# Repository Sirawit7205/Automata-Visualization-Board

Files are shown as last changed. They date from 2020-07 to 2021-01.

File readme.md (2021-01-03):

# CMOS Elementary Automata Visualization Board

This is an  open-source KiCad design files for a circuit that could generate and visualize [Elementary Automata](https://mathworld.wolfram.com/ElementaryCellularAutomaton.html) only by using common logic ICs. There are two versions available: Standard and Minimal. 

## Standard Version

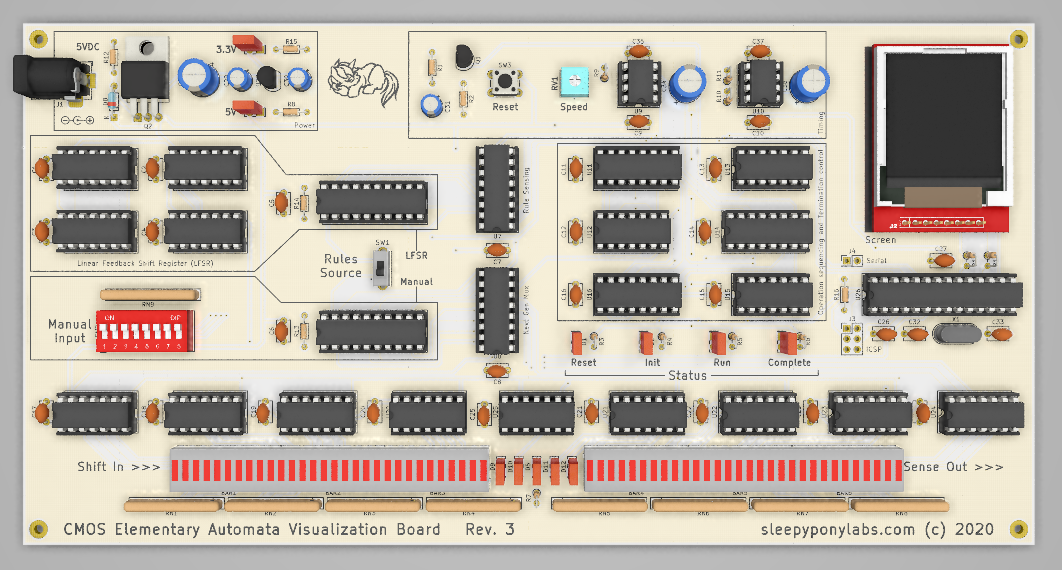
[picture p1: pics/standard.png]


Standard version is a large board of size 247x127mm (9.7x5in), suitable for putting in a frame. Featuring:

 - 26 Logic ICs in DIP package. (Okay, I have an ATMEGA328 here but it's here just to drive the display. Its firmware is available here as well.)
 - 1.44 inch TFT display with a display driver which can draws a complete picture of that elementary automata rule.
 - Fully visualized 65-bit shift register so you can see how the data flows.
 - Fully selectable 8-bit automata rule input.
 - An LSFR pseudo-random rules generator.
 - Status display.
 - Drawing speed adjustment.
 - All through hole design. Should be relatively easy to solder.

We are currently at Revision 3. Changelog is below:

**Revision 3 (July 2020)**
 - Fixed all of the issues found in rev 2.
 - BOMs consolidated to lessen the unique parts count.
 - New LFSR circuit, the rare CD4006 is no longer required.
 - Updated all footprints to the latest version.
 - Minor changes to the appearances of the PCB.

**Revision 2 (May 2020)**
 - Fixed Connector orientation for the display and the DIP switch.
 - Connected GND to mounting holes
 - Change of parts in the power section due to sourcing issue.
 
**Revision 1 (January 2020)**
 - Initial Design

## Minimal Version

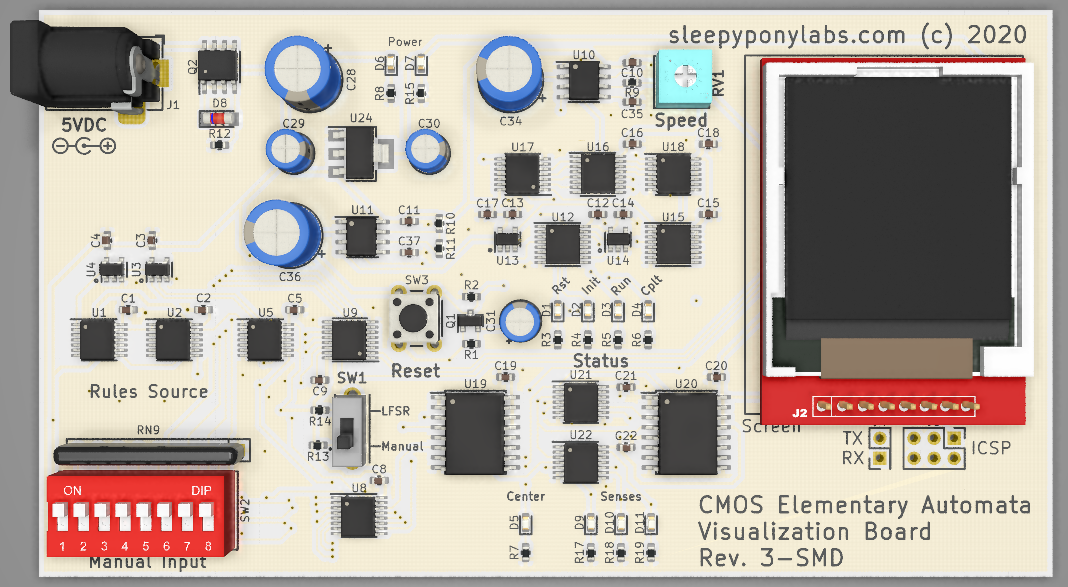
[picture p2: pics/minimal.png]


Minimal Version is a smaller board of size 129x72mm (5x3in). It is suitable for carrying around to show off. Featuring:

 - 23 Logic ICs in SOT, SOIC, TSSOP, and TQFP packages.
 - 1.44 inch TFT display.
 - Fully selectable 8-bit automata rule input.
 - An LSFR pseudo-random rules generator.
 - Status display.
 - Drawing speed adjustment.
 - Very challenging SMD soldering practice kit.
 - The PCB should be much cheaper to produce. It's still a little bit too large to fit in 10x10cm requirements for many cheap PCB fabs though, I might try to squeeze it down later.

We are currently at Revision 3. Changelog is below:

**Revision 3 (July 2020)**
 - Fixed all of the issues found in smd rev 2.
 - BOMs consolidated to lessen the unique parts count.
 - New LFSR circuit, the rare CD4006 is no longer required.
 - Updated all footprints to the latest version.
 - Minor changes to the appearances of the PCB.

**Revision 2 (May 2020)**
 - Fixed all of the issues found in rev 1 of the Standard version.
 - Change of parts in the power section due to sourcing issue.
 
**Revision 1 (April 2020)**
 - Initial Design (Based on Standard version)

## What is provided
The goal of this repository is to enable you to build this on your own as easy as possible (although I originally plan to sell this as a kit as well). **I've included all of the schematics, gerbers, BOMs, and display driver firmware for you to use.** And this work is licensed under a [Creative Commons Attribution-NonCommercial 4.0 International License](http://creativecommons.org/licenses/by-nc/4.0/).

Unfortunately. I have to excluded the 3D models use to render the board in KiCAD because I don't know how each of them was licensed. They are all from GrabCad and you could search and download them by yourself.

**Note: Due to this, there might be a popup warning you about "3D model Search Path" in PCBNew. I honestly don't know how to fix this but it will not affect any KiCAD functionality.**

## Credits
 - DIP switch model by austfox: https://grabcad.com/library/dip-switches-1
 - 1.44inch LCD model by John: https://grabcad.com/library/1-44in-lcd-tft-1
 - Sliding switch model by Jonn: https://grabcad.com/library/selector-switch-assortment-1
 - Trimpot model by Markus Walter: https://grabcad.com/library/bourns-3362p-1-102lf
 - DIP ICs in socket models by Dirk Wouters: https://grabcad.com/library/ic-dip-packages-with-sockets-in-pitch-7-62mm-1
 - TO-220 package model by Egor Chugay: https://grabcad.com/library/to-220-transistor-package-1
 - DC Power Jack model by J. F. Gomez: https://grabcad.com/library/dc-power-jack-5-5mm-x-2-1mm-2-54mm-pitch-1
 - SMD 5032 Crystal 2-Pin model by Dirk Wouters: https://grabcad.com/library/smd-5032-crystal-2-pin-1
 - LED Bar Graph model by austfox: https://grabcad.com/library/led-bar-graph-2
 - 3306P1102, 3362P_1, NE555DR, OS102011MA1QN1, TO229P239X654X978-3P footprint symbols by SamacSys

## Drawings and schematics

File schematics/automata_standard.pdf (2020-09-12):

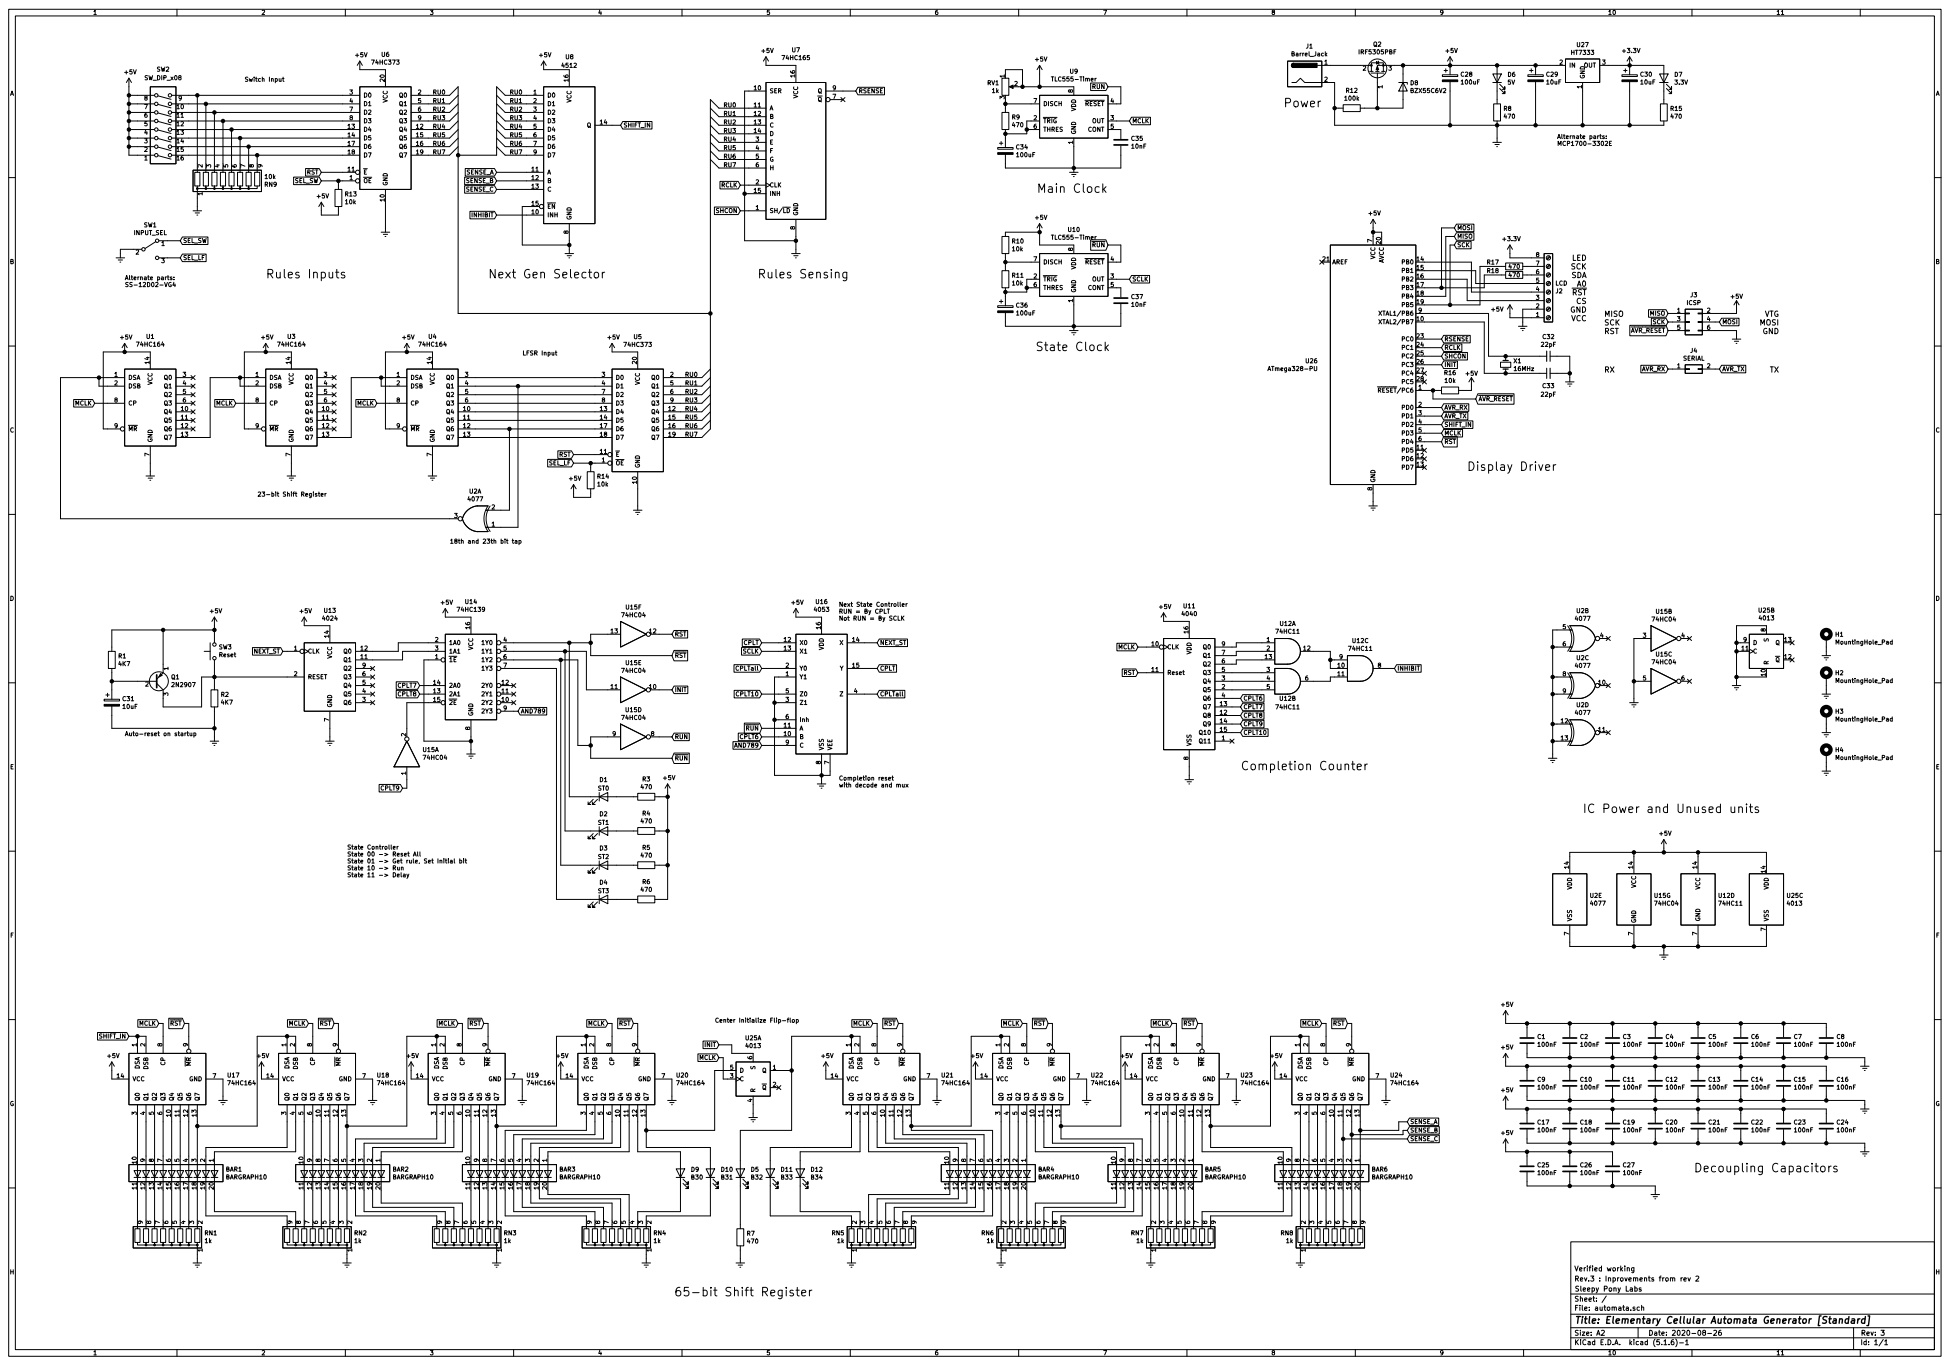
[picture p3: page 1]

1 TRIG 2 OUT 3 RESET 4 CONT 5 THRES 6 DISCH 7 VDD

Completion Counter Next State Controller RUN = By CPLT

Not RUN = By SCLK

INHIBIT RST CPLT RUN

Auto-reset on startup

IC Power and Unused units

State Controller State 00 -> Reset All State 01 -> Get rule, Set Initial bit State 10 -> Run State 11 -> Delay

Center Initialize Flip-flop

Verified working
Rev.3 : Inprovements from rev 2
Id: 1/1 Title: Elementary Cellular Automata Generator [Standard] File: automata.sch Sheet: / Sleepy Pony Labs

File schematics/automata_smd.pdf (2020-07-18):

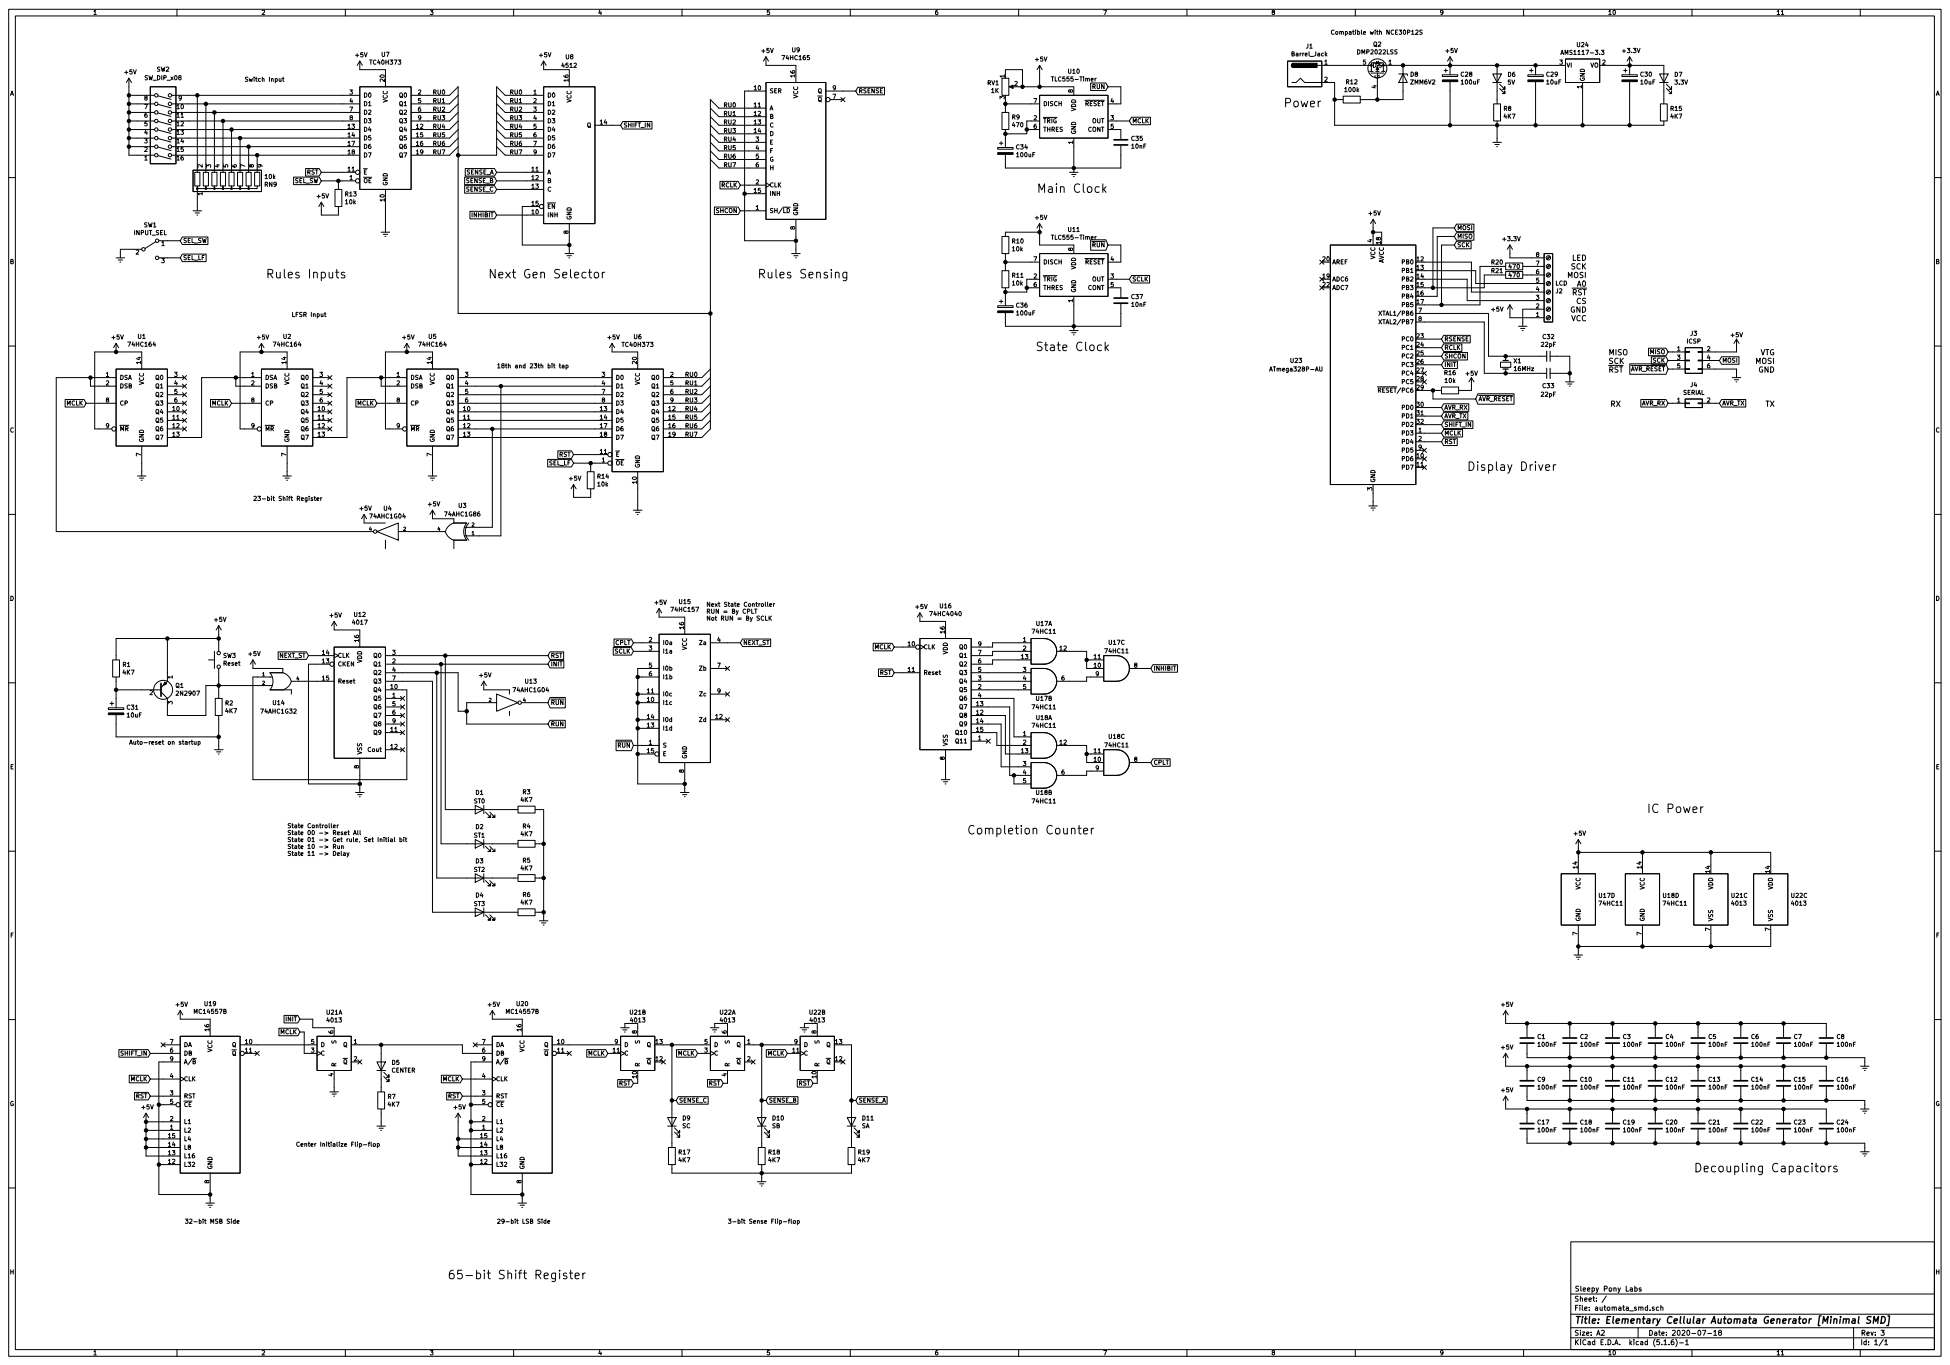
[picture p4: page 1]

1 TRIG 2 OUT 3 RESET 4 CONT 5 THRES 6 DISCH 7 VDD

14 PB3
15 PB4

Not RUN = By SCLK

Auto-reset on startup

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

Center Initialize Flip-flop

3-bit Sense Flip-flop

Id: 1/1 Title: Elementary Cellular Automata Generator [Minimal SMD]

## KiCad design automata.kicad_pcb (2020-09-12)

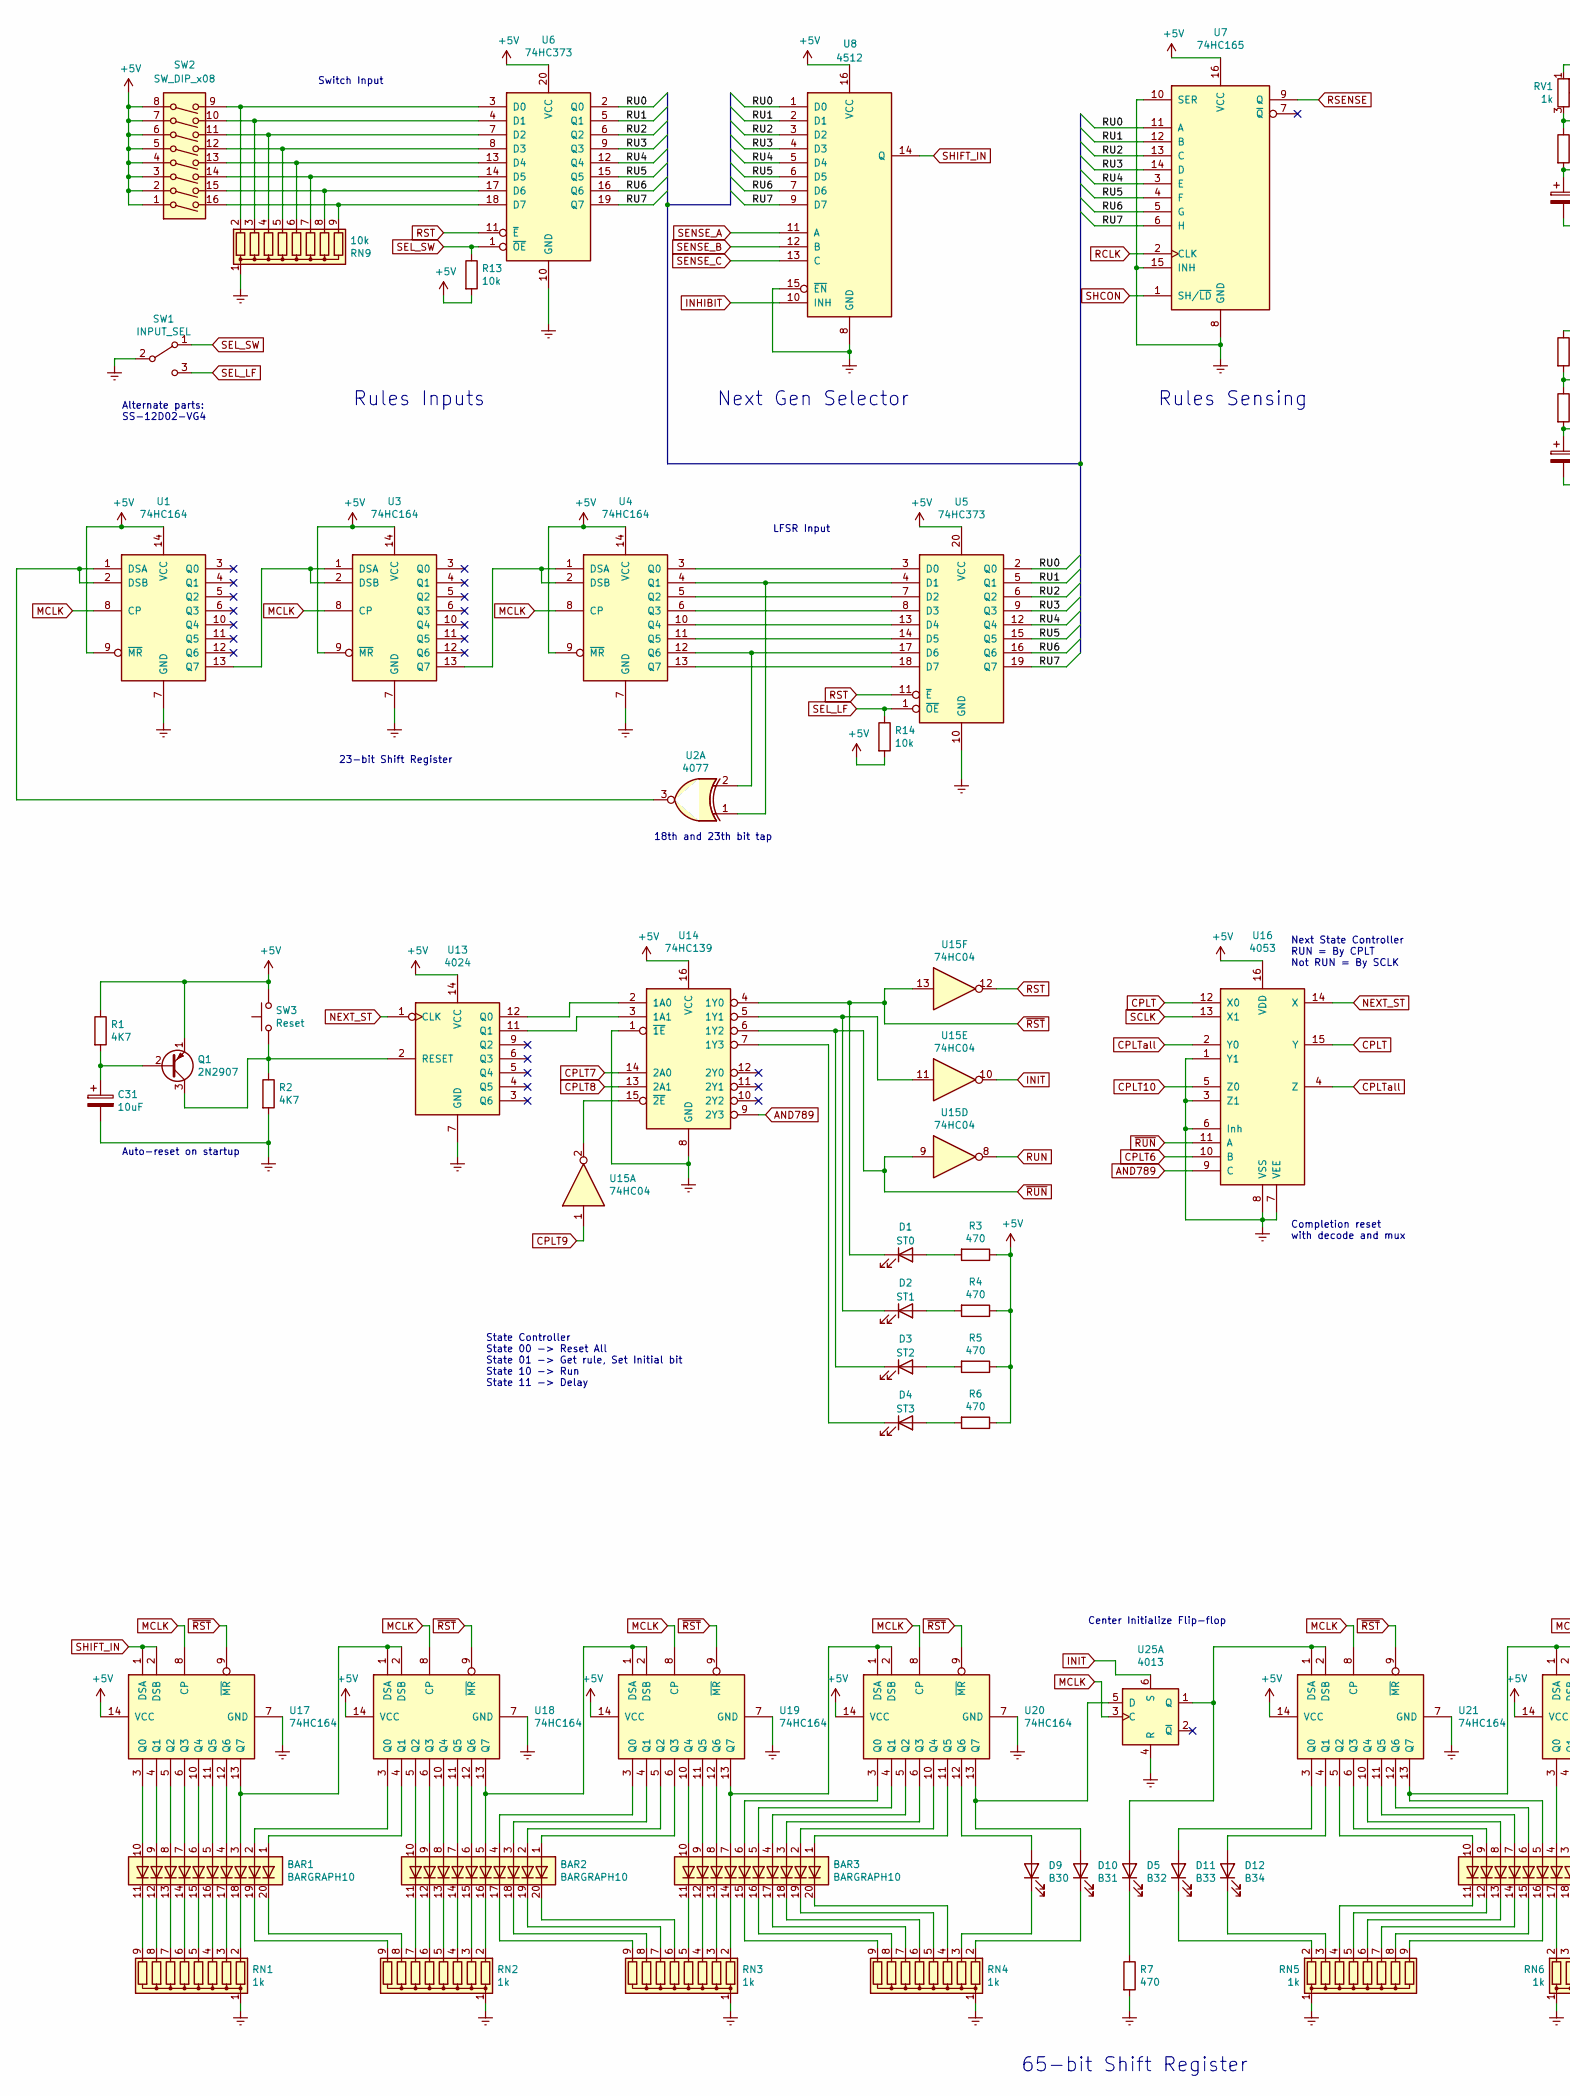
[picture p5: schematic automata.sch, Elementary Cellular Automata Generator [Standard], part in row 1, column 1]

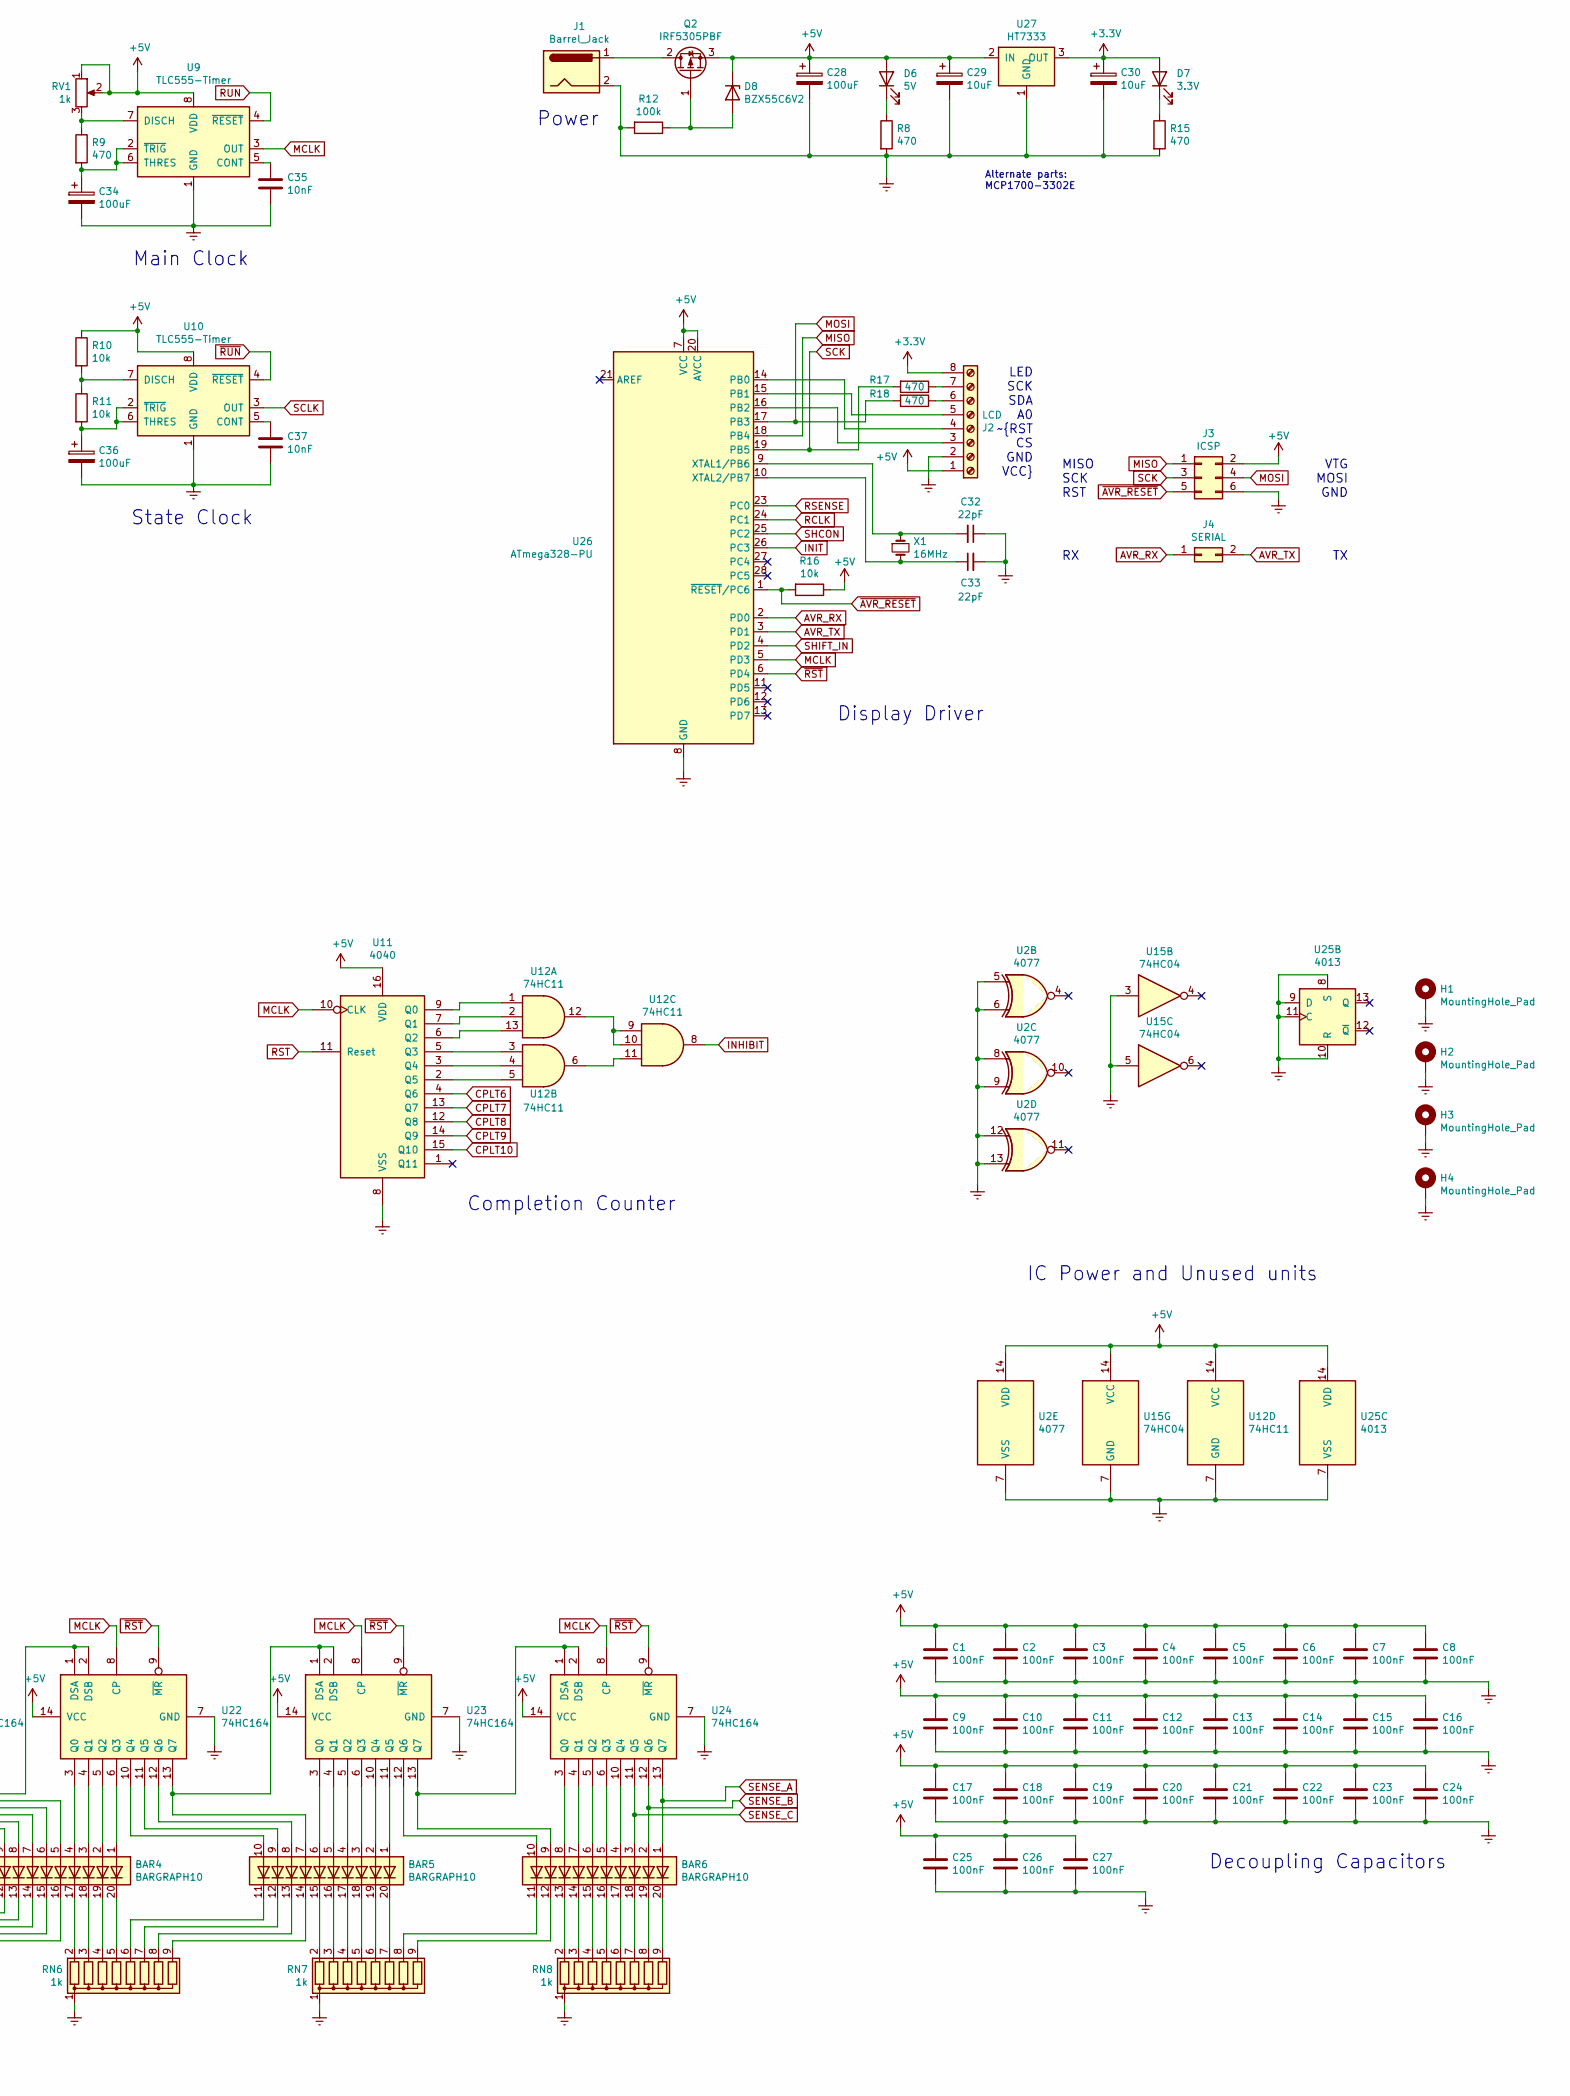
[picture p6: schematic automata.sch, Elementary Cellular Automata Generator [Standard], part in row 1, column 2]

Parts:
BAR1, BAR2, BAR3, BAR4, BAR5, BAR6: BARGRAPH10; BARGRAPH_DIP_10
C1, C2, C3, C4, C5, C6, C7, C8, C9, C10, C11, C12, C13, C14, C15, C16, C17, C18, C19, C20, C21, C22, C23, C24, C25, C26, C27: 100nF; C_Disc_D5.1mm_W3.2mm_P5.00mm
C28, C34, C36: 100uF; CP_Radial_D8.0mm_P2.50mm
C29, C30, C31: 10uF; CP_Radial_D5.0mm_P2.00mm
C32, C33: 22pF; C_Disc_D5.1mm_W3.2mm_P5.00mm
C35, C37: 10nF; C_Disc_D5.1mm_W3.2mm_P5.00mm
D1: ST0; LED_Rectangular_W5.0mm_H2.0mm
D2: ST1; LED_Rectangular_W5.0mm_H2.0mm
D3: ST2; LED_Rectangular_W5.0mm_H2.0mm
D4: ST3; LED_Rectangular_W5.0mm_H2.0mm
D5: B32; LED_Rectangular_W5.0mm_H2.0mm
D6: 5V; LED_Rectangular_W5.0mm_H2.0mm
D7: 3.3V; LED_Rectangular_W5.0mm_H2.0mm
D8: BZX55C6V2; D_DO-35_SOD27_P7.62mm_Horizontal
D9: B30; LED_Rectangular_W5.0mm_H2.0mm
D10: B31; LED_Rectangular_W5.0mm_H2.0mm
D11: B33; LED_Rectangular_W5.0mm_H2.0mm
D12: B34; LED_Rectangular_W5.0mm_H2.0mm
H1, H2, H3, H4: MountingHole_Pad; MountingHole_2.2mm_M2_Pad
J1: Barrel_Jack; BarrelJack_Horizontal
J2: LCD; PinHeader_1x08_P2.54mm_Vertical
J3: ICSP; PinHeader_2x03_P2.54mm_Vertical
J4: SERIAL; PinHeader_2x01_P2.54mm_Vertical
Q1: 2N2907; TO-92_Inline
Q2: IRF5305PBF; TO-220-3_Horizontal_TabDown
R1, R2: 4K7; R_Axial_DIN0204_L3.6mm_D1.6mm_P7.62mm_Horizontal
R3, R4, R5, R6, R7, R9, R17, R18: 470; R_Axial_DIN0204_L3.6mm_D1.6mm_P2.54mm_Vertical
R8, R15: 470; R_Axial_DIN0204_L3.6mm_D1.6mm_P7.62mm_Horizontal
R10, R11: 10k; R_Axial_DIN0204_L3.6mm_D1.6mm_P2.54mm_Vertical
R12: 100k; R_Axial_DIN0204_L3.6mm_D1.6mm_P7.62mm_Horizontal
R13, R14, R16: 10k; R_Axial_DIN0204_L3.6mm_D1.6mm_P7.62mm_Horizontal
RN1, RN2, RN3, RN4, RN5, RN6, RN7, RN8: 1k; R_Array_SIP9
RN9: 10k; R_Array_SIP9
RV1: 1k; 3362P_1
SW1: INPUT_SEL; OS102011MA1QN1
SW2: SW_DIP_x08; SW_DIP_SPSTx08_Slide_9.78x22.5mm_W7.62mm_P2.54mm
SW3: Reset; SW_PUSH_6mm
U1, U3, U4, U17, U18, U19, U20, U21, U22, U23, U24: 74HC164; DIP-14_W7.62mm_Socket
U2: 4077; DIP-14_W7.62mm_Socket
U5, U6: 74HC373; DIP-20_W7.62mm_Socket
U7: 74HC165; DIP-16_W7.62mm_Socket
U8: 4512; DIP-16_W7.62mm_Socket
U9, U10: TLC555-Timer; DIP-8_W7.62mm_Socket
U11: 4040; DIP-16_W7.62mm_Socket
U12: 74HC11; DIP-14_W7.62mm_Socket
U13: 4024; DIP-14_W7.62mm_Socket
U14: 74HC139; DIP-16_W7.62mm_Socket
U15: 74HC04; DIP-14_W7.62mm_Socket
U16: 4053; DIP-16_W7.62mm_Socket
U25: 4013; DIP-14_W7.62mm_Socket
U26: ATmega328-PU; DIP-28_W7.62mm_Socket
U27: HT7333; TO-92_Inline
X1: 16MHz; Crystal_HC49-4H_Vertical

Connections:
+3V3: C30.1, D7.2 (A), J2.8, U27.3 (OUT)
+5V: C1.1, C2.1, C3.1, C4.1, C5.1, C6.1, C7.1, C8.1, C9.1, C10.1, C11.1, C12.1, C13.1, C14.1, C15.1, C16.1, C17.1, C18.1, C19.1, C20.1, C21.1, C22.1, C23.1, C24.1, C25.1, C26.1, C27.1, C28.1, C29.1, D6.2 (A), D8.1 (K), J2.1, J3.2, Q1.1 (E), Q2.3 (S), R1.1, R3.1, R4.1, R5.1, R6.1, R10.1, R13.2, R14.2, R16.1, RV1.1, RV1.2, SW2.1, SW2.2, SW2.3, SW2.4, SW2.5, SW2.6, SW2.7, SW2.8, SW3.2, U1.9 (~MR), U1.14 (VCC), U2.14 (VDD), U3.9 (~MR), U3.14 (VCC), U4.9 (~MR), U4.14 (VCC), U5.20 (VCC), U6.20 (VCC), U7.16 (VCC), U8.16 (VCC), U9.8 (VDD), U10.8 (VDD), U11.16 (VDD), U12.14 (VCC), U13.14 (VCC), U14.16 (VCC), U15.14 (VCC), U16.16 (VDD), U17.14 (VCC), U18.14 (VCC), U19.14 (VCC), U20.14 (VCC), U21.14 (VCC), U22.14 (VCC), U23.14 (VCC), U24.14 (VCC), U25.14 (VDD), U26.7 (VCC), U26.20 (AVCC), U27.2 (IN)
/RU0: U5.2 (Q0), U6.2 (Q0), U7.11 (A), U8.1 (D0)
/RU1: U5.5 (Q1), U6.5 (Q1), U7.12 (B), U8.2 (D1)
/RU2: U5.6 (Q2), U6.6 (Q2), U7.13 (C), U8.3 (D2)
/RU3: U5.9 (Q3), U6.9 (Q3), U7.14 (D), U8.4 (D3)
/RU4: U5.12 (Q4), U6.12 (Q4), U7.3 (E), U8.5 (D4)
/RU5: U5.15 (Q5), U6.15 (Q5), U7.4 (F), U8.6 (D5)
/RU6: U5.16 (Q6), U6.16 (Q6), U7.5 (G), U8.7 (D6)
/RU7: U5.19 (Q7), U6.19 (Q7), U7.6 (H), U8.9 (D7)
AND789: U14.9 (2Y3), U16.9 (C)
AVR_RX: J4.1, U26.2 (PD0)
AVR_TX: J4.2, U26.3 (PD1)
CPLT: U16.12 (X0), U16.15 (Y)
CPLT6: U11.4 (Q6), U16.10 (B)
CPLT7: U11.13 (Q7), U14.14 (2A0)
CPLT8: U11.12 (Q8), U14.13 (2A1)
CPLT9: U11.14 (Q9), U15.1
CPLT10: U11.15 (Q10), U16.5 (Z0)
CPLTall: U16.2 (Y0), U16.4 (Z)
GNDREF: C1.2, C2.2, C3.2, C4.2, C5.2, C6.2, C7.2, C8.2, C9.2, C10.2, C11.2, C12.2, C13.2, C14.2, C15.2, C16.2, C17.2, C18.2, C19.2, C20.2, C21.2, C22.2, C23.2, C24.2, C25.2, C26.2, C27.2, C28.2, C29.2, C30.2, C31.2, C32.1, C33.2, C34.2, C35.2, C36.2, C37.2, H1.1, H2.1, H3.1, H4.1, J1.2, J2.2, J3.6, R2.2, R7.2, R8.2, R12.2, R15.2, RN1.1 (common), RN2.1 (common), RN3.1 (common), RN4.1 (common), RN5.1 (common), RN6.1 (common), RN7.1 (common), RN8.1 (common), RN9.1 (common), SW1.2 (B), U1.7 (GND), U2.5, U2.6, U2.7 (VSS), U2.8, U2.9, U2.12, U2.13, U3.7 (GND), U4.7 (GND), U5.10 (GND), U6.10 (GND), U7.8 (GND), U7.10 (SER), U7.15 (INH), U8.8 (GND), U8.15 (~EN), U9.1 (GND), U10.1 (GND), U11.8 (VSS), U12.7 (GND), U13.7 (GND), U14.1 (~1E), U14.8 (GND), U15.3, U15.5, U15.7 (GND), U16.1 (Y1), U16.3 (Z1), U16.6 (Inh), U16.7 (VEE), U16.8 (VSS), U17.7 (GND), U18.7 (GND), U19.7 (GND), U20.7 (GND), U21.7 (GND), U22.7 (GND), U23.7 (GND), U24.7 (GND), U25.4 (R), U25.7 (VSS), U25.8 (S), U25.9 (D), U25.10 (R), U25.11 (C), U26.8 (GND), U26.22 (GND), U27.1 (GND)
INHIBIT: U8.10 (INH), U12.8
INIT: U15.10, U25.6 (S), U26.26 (PC3)
MCLK: U1.8 (CP), U3.8 (CP), U4.8 (CP), U9.3 (OUT), U11.10 (CLK), U17.8 (CP), U18.8 (CP), U19.8 (CP), U20.8 (CP), U21.8 (CP), U22.8 (CP), U23.8 (CP), U24.8 (CP), U25.3 (C), U26.5 (PD3)
MISO: J3.1, U26.18 (PB4)
MOSI: J3.4, R18.2, U26.17 (PB3)
NEXT_ST: U13.1 (CLK), U16.14 (X)
unnamed: BAR1.1 (A), U18.4 (Q1)
unnamed: BAR1.2 (A), U18.3 (Q0)
unnamed: BAR1.3 (A), U17.13 (Q7), U18.1 (DSA), U18.2 (DSB)
unnamed: BAR1.4 (A), U17.12 (Q6)
unnamed: BAR1.5 (A), U17.11 (Q5)
unnamed: BAR1.6 (A), U17.10 (Q4)
unnamed: BAR1.7 (A), U17.6 (Q3)
unnamed: BAR1.8 (A), U17.5 (Q2)
unnamed: BAR1.9 (A), U17.4 (Q1)
unnamed: BAR1.10 (A), U17.3 (Q0)
unnamed: BAR1.11 (K), RN1.9 (R8)
unnamed: BAR1.12 (K), RN1.8 (R7)
unnamed: BAR1.13 (K), RN1.7 (R6)
unnamed: BAR1.14 (K), RN1.6 (R5)
unnamed: BAR1.15 (K), RN1.5 (R4)
unnamed: BAR1.16 (K), RN1.4 (R3)
unnamed: BAR1.17 (K), RN1.3 (R2)
unnamed: BAR1.18 (K), RN1.2 (R1)
unnamed: BAR1.19 (K), RN2.9 (R8)
unnamed: BAR1.20 (K), RN2.8 (R7)
unnamed: BAR2.1 (A), U19.6 (Q3)
unnamed: BAR2.2 (A), U19.5 (Q2)
unnamed: BAR2.3 (A), U19.4 (Q1)
unnamed: BAR2.4 (A), U19.3 (Q0)
unnamed: BAR2.5 (A), U18.13 (Q7), U19.1 (DSA), U19.2 (DSB)
unnamed: BAR2.6 (A), U18.12 (Q6)
unnamed: BAR2.7 (A), U18.11 (Q5)
unnamed: BAR2.8 (A), U18.10 (Q4)
unnamed: BAR2.9 (A), U18.6 (Q3)
unnamed: BAR2.10 (A), U18.5 (Q2)
unnamed: BAR2.11 (K), RN2.7 (R6)
unnamed: BAR2.12 (K), RN2.6 (R5)
unnamed: BAR2.13 (K), RN2.5 (R4)
unnamed: BAR2.14 (K), RN2.4 (R3)
unnamed: BAR2.15 (K), RN2.3 (R2)
unnamed: BAR2.16 (K), RN2.2 (R1)
unnamed: BAR2.17 (K), RN3.9 (R8)
unnamed: BAR2.18 (K), RN3.8 (R7)
unnamed: BAR2.19 (K), RN3.7 (R6)
unnamed: BAR2.20 (K), RN3.6 (R5)
unnamed: BAR3.1 (A), U20.11 (Q5)
unnamed: BAR3.2 (A), U20.10 (Q4)
unnamed: BAR3.3 (A), U20.6 (Q3)
unnamed: BAR3.4 (A), U20.5 (Q2)
unnamed: BAR3.5 (A), U20.4 (Q1)
unnamed: BAR3.6 (A), U20.3 (Q0)
unnamed: BAR3.7 (A), U19.13 (Q7), U20.1 (DSA), U20.2 (DSB)
unnamed: BAR3.8 (A), U19.12 (Q6)
unnamed: BAR3.9 (A), U19.11 (Q5)
unnamed: BAR3.10 (A), U19.10 (Q4)
unnamed: BAR3.11 (K), RN3.5 (R4)
unnamed: BAR3.12 (K), RN3.4 (R3)
unnamed: BAR3.13 (K), RN3.3 (R2)
unnamed: BAR3.14 (K), RN3.2 (R1)
unnamed: BAR3.15 (K), RN4.9 (R8)
unnamed: BAR3.16 (K), RN4.8 (R7)
unnamed: BAR3.17 (K), RN4.7 (R6)
unnamed: BAR3.18 (K), RN4.6 (R5)
unnamed: BAR3.19 (K), RN4.5 (R4)
unnamed: BAR3.20 (K), RN4.4 (R3)
unnamed: BAR4.1 (A), U22.6 (Q3)
unnamed: BAR4.2 (A), U22.5 (Q2)
unnamed: BAR4.3 (A), U22.4 (Q1)
unnamed: BAR4.4 (A), U22.3 (Q0)
unnamed: BAR4.5 (A), U21.13 (Q7), U22.1 (DSA), U22.2 (DSB)
unnamed: BAR4.6 (A), U21.12 (Q6)
unnamed: BAR4.7 (A), U21.11 (Q5)
unnamed: BAR4.8 (A), U21.10 (Q4)
unnamed: BAR4.9 (A), U21.6 (Q3)
unnamed: BAR4.10 (A), U21.5 (Q2)
unnamed: BAR4.11 (K), RN5.4 (R3)
unnamed: BAR4.12 (K), RN5.5 (R4)
unnamed: BAR4.13 (K), RN5.6 (R5)
unnamed: BAR4.14 (K), RN5.7 (R6)
unnamed: BAR4.15 (K), RN5.8 (R7)
unnamed: BAR4.16 (K), RN5.9 (R8)
unnamed: BAR4.17 (K), RN6.2 (R1)
unnamed: BAR4.18 (K), RN6.3 (R2)
unnamed: BAR4.19 (K), RN6.4 (R3)
unnamed: BAR4.20 (K), RN6.5 (R4)
unnamed: BAR5.1 (A), U23.11 (Q5)
unnamed: BAR5.2 (A), U23.10 (Q4)
unnamed: BAR5.3 (A), U23.6 (Q3)
unnamed: BAR5.4 (A), U23.5 (Q2)
unnamed: BAR5.5 (A), U23.4 (Q1)
unnamed: BAR5.6 (A), U23.3 (Q0)
unnamed: BAR5.7 (A), U22.13 (Q7), U23.1 (DSA), U23.2 (DSB)
unnamed: BAR5.8 (A), U22.12 (Q6)
unnamed: BAR5.9 (A), U22.11 (Q5)
unnamed: BAR5.10 (A), U22.10 (Q4)
unnamed: BAR5.11 (K), RN6.6 (R5)
unnamed: BAR5.12 (K), RN6.7 (R6)
unnamed: BAR5.13 (K), RN6.8 (R7)
unnamed: BAR5.14 (K), RN6.9 (R8)
unnamed: BAR5.15 (K), RN7.2 (R1)
unnamed: BAR5.16 (K), RN7.3 (R2)
unnamed: BAR5.17 (K), RN7.4 (R3)
unnamed: BAR5.18 (K), RN7.5 (R4)
unnamed: BAR5.19 (K), RN7.6 (R5)
unnamed: BAR5.20 (K), RN7.7 (R6)
unnamed: BAR6.4 (A), U24.10 (Q4)
unnamed: BAR6.5 (A), U24.6 (Q3)
unnamed: BAR6.6 (A), U24.5 (Q2)
unnamed: BAR6.7 (A), U24.4 (Q1)
unnamed: BAR6.8 (A), U24.3 (Q0)
unnamed: BAR6.9 (A), U23.13 (Q7), U24.1 (DSA), U24.2 (DSB)
unnamed: BAR6.10 (A), U23.12 (Q6)
unnamed: BAR6.11 (K), RN7.8 (R7)
unnamed: BAR6.12 (K), RN7.9 (R8)
unnamed: BAR6.13 (K), RN8.2 (R1)
unnamed: BAR6.14 (K), RN8.3 (R2)
unnamed: BAR6.15 (K), RN8.4 (R3)
unnamed: BAR6.16 (K), RN8.5 (R4)
unnamed: BAR6.17 (K), RN8.6 (R5)
unnamed: BAR6.18 (K), RN8.7 (R6)
unnamed: BAR6.19 (K), RN8.8 (R7)
unnamed: BAR6.20 (K), RN8.9 (R8)
unnamed: C31.1, Q1.2 (B), R1.2
unnamed: C32.2, U26.9 (XTAL1/PB6), X1.1
unnamed: C33.1, U26.10 (XTAL2/PB7), X1.2
unnamed: C34.1, R9.2, U9.2 (~TRIG), U9.6 (THRES)
unnamed: C35.1, U9.5 (CONT)
unnamed: C36.1, R11.2, U10.2 (~TRIG), U10.6 (THRES)
unnamed: C37.1, U10.5 (CONT)
unnamed: D1.2 (A), R3.2
unnamed: D2.1 (K), U14.5 (1Y1), U15.11
unnamed: D2.2 (A), R4.2
unnamed: D3.2 (A), R5.2
unnamed: D4.1 (K), U14.7 (1Y3)
unnamed: D4.2 (A), R6.2
unnamed: D5.1 (K), R7.1
unnamed: D5.2 (A), U21.1 (DSA), U21.2 (DSB), U25.1 (Q)
unnamed: D6.1 (K), R8.1
unnamed: D7.1 (K), R15.1
unnamed: D8.2 (A), Q2.1 (G), R12.1
unnamed: D9.1 (K), RN4.3 (R2)
unnamed: D9.2 (A), U20.12 (Q6)
unnamed: D10.1 (K), RN4.2 (R1)
unnamed: D10.2 (A), U20.13 (Q7), U25.5 (D)
unnamed: D11.1 (K), RN5.2 (R1)
unnamed: D11.2 (A), U21.3 (Q0)
unnamed: D12.1 (K), RN5.3 (R2)
unnamed: D12.2 (A), U21.4 (Q1)
unnamed: J1.1, Q2.2 (D)
unnamed: J2.3, U26.16 (PB2)
unnamed: J2.4, U26.14 (PB0)
unnamed: J2.5, U26.15 (PB1)
unnamed: J2.6, R18.1
unnamed: J2.7, R17.1
unnamed: Q1.3 (C), R2.1, SW3.1, U13.2 (RESET)
unnamed: R9.1, RV1.3, U9.7 (DISCH)
unnamed: R10.2, R11.1, U10.7 (DISCH)
unnamed: RN9.2 (R1), SW2.9, U6.3 (D0)
unnamed: RN9.3 (R2), SW2.10, U6.4 (D1)
unnamed: RN9.4 (R3), SW2.11, U6.7 (D2)
unnamed: RN9.5 (R4), SW2.12, U6.8 (D3)
unnamed: RN9.6 (R5), SW2.13, U6.13 (D4)
unnamed: RN9.7 (R6), SW2.14, U6.14 (D5)
unnamed: RN9.8 (R7), SW2.15, U6.17 (D6)
unnamed: RN9.9 (R8), SW2.16, U6.18 (D7)
unnamed: U1.1 (DSA), U1.2 (DSB), U2.3
unnamed: U1.13 (Q7), U3.1 (DSA), U3.2 (DSB)
unnamed: U2.1, U4.4 (Q1), U5.4 (D1)
unnamed: U2.2, U4.12 (Q6), U5.17 (D6)
unnamed: U3.13 (Q7), U4.1 (DSA), U4.2 (DSB)
unnamed: U4.3 (Q0), U5.3 (D0)
unnamed: U4.5 (Q2), U5.7 (D2)
unnamed: U4.6 (Q3), U5.8 (D3)
unnamed: U4.10 (Q4), U5.13 (D4)
unnamed: U4.11 (Q5), U5.14 (D5)
unnamed: U4.13 (Q7), U5.18 (D7)
unnamed: U11.2 (Q5), U12.5
unnamed: U11.3 (Q4), U12.4
unnamed: U11.5 (Q3), U12.3
unnamed: U11.6 (Q2), U12.13
unnamed: U11.7 (Q1), U12.2
unnamed: U11.9 (Q0), U12.1
unnamed: U12.9, U12.10, U12.12
unnamed: U12.6, U12.11
unnamed: U13.11 (Q1), U14.3 (1A1)
unnamed: U13.12 (Q0), U14.2 (1A0)
unnamed: U14.15 (~2E), U15.2
RCLK: U7.2 (CLK), U26.24 (PC1)
RSENSE: U7.9 (Q), U26.23 (PC0)
RST: U5.11 (~E), U6.11 (~E), U11.11 (Reset), U15.12
RUN: U9.4 (~RESET), U15.8
SCK: J3.3, R17.2, U26.19 (PB5)
SCLK: U10.3 (OUT), U16.13 (X1)
SEL_LF: R14.1, SW1.3 (C), U5.1 (~OE)
SEL_SW: R13.1, SW1.1 (A), U6.1 (~OE)
SENSE_A: BAR6.1 (A), U8.11 (A), U24.13 (Q7)
SENSE_B: BAR6.2 (A), U8.12 (B), U24.12 (Q6)
SENSE_C: BAR6.3 (A), U8.13 (C), U24.11 (Q5)
SHCON: U7.1 (SH/~LD), U26.25 (PC2)
SHIFT_IN: U8.14 (Q), U17.1 (DSA), U17.2 (DSB), U26.4 (PD2)
~AVR_RESET: J3.5, R16.2, U26.1 (~RESET~/PC6)
~RST: D1.1 (K), U14.4 (1Y0), U15.13, U17.9 (~MR), U18.9 (~MR), U19.9 (~MR), U20.9 (~MR), U21.9 (~MR), U22.9 (~MR), U23.9 (~MR), U24.9 (~MR), U26.6 (PD4)
~RUN: D3.1 (K), U10.4 (~RESET), U14.6 (1Y2), U15.9, U16.11 (A)

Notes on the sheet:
Switch Input
Rules Inputs
Next Gen Selector
Completion Counter
LED SCK SDA A0 ~RST CS GND VCC
Power
Display Driver
Rules Sensing
State Controller State 00 -> Reset All State 01 -> Get rule, Set Initial bit State 10 -> Run State 11 -> Delay
Auto-reset on startup
State Clock
Next State Controller RUN = By CPLT Not RUN = By SCLK
65-bit Shift Register
Center Initialize Flip-flop
Completion reset with decode and mux
Main Clock
Decoupling Capacitors
IC Power and Unused units
VTG MOSI GND
MISO SCK RST
23-bit Shift Register
18th and 23th bit tap
LFSR Input
Alternate parts: MCP1700-3302E
Alternate parts: SS-12D02-VG4

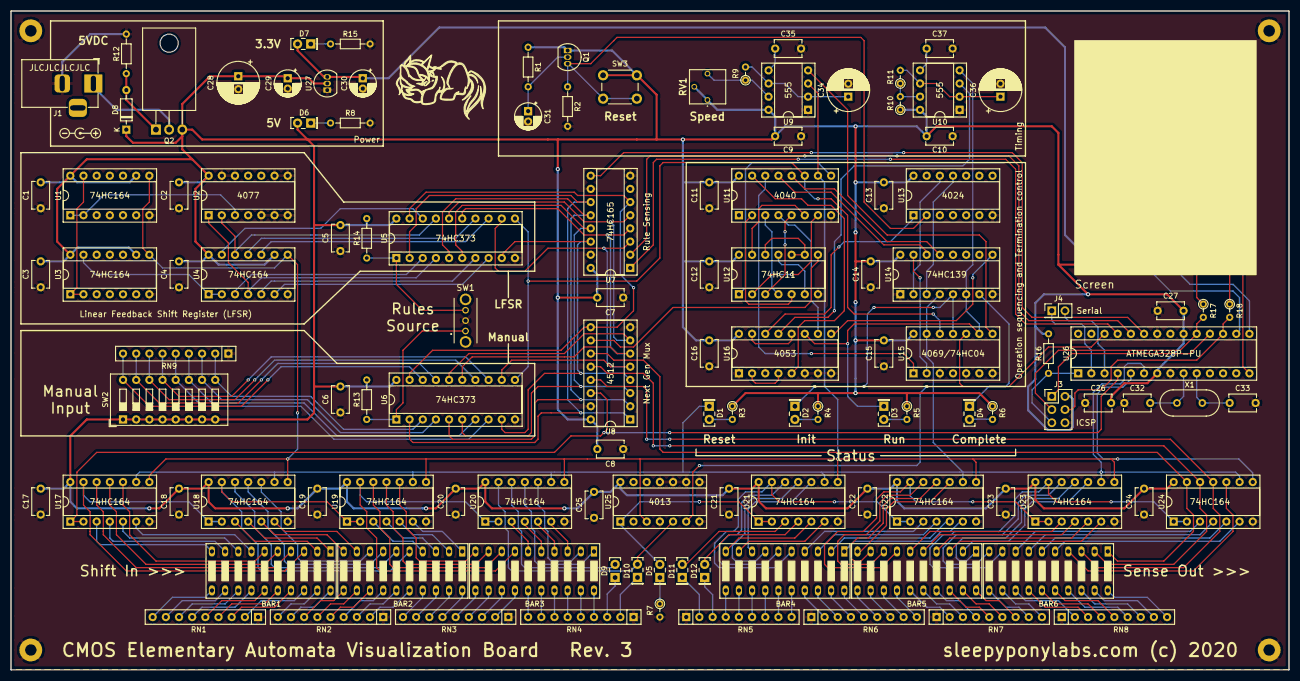
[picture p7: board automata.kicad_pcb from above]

Board: 2 copper layers, 246.4 x 127.0 mm, 126 parts (0 on the bottom side), 225 nets.

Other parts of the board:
G1: LOGO; sleepylogo_20mm
REF1: Symbol_Barrel_Polarity

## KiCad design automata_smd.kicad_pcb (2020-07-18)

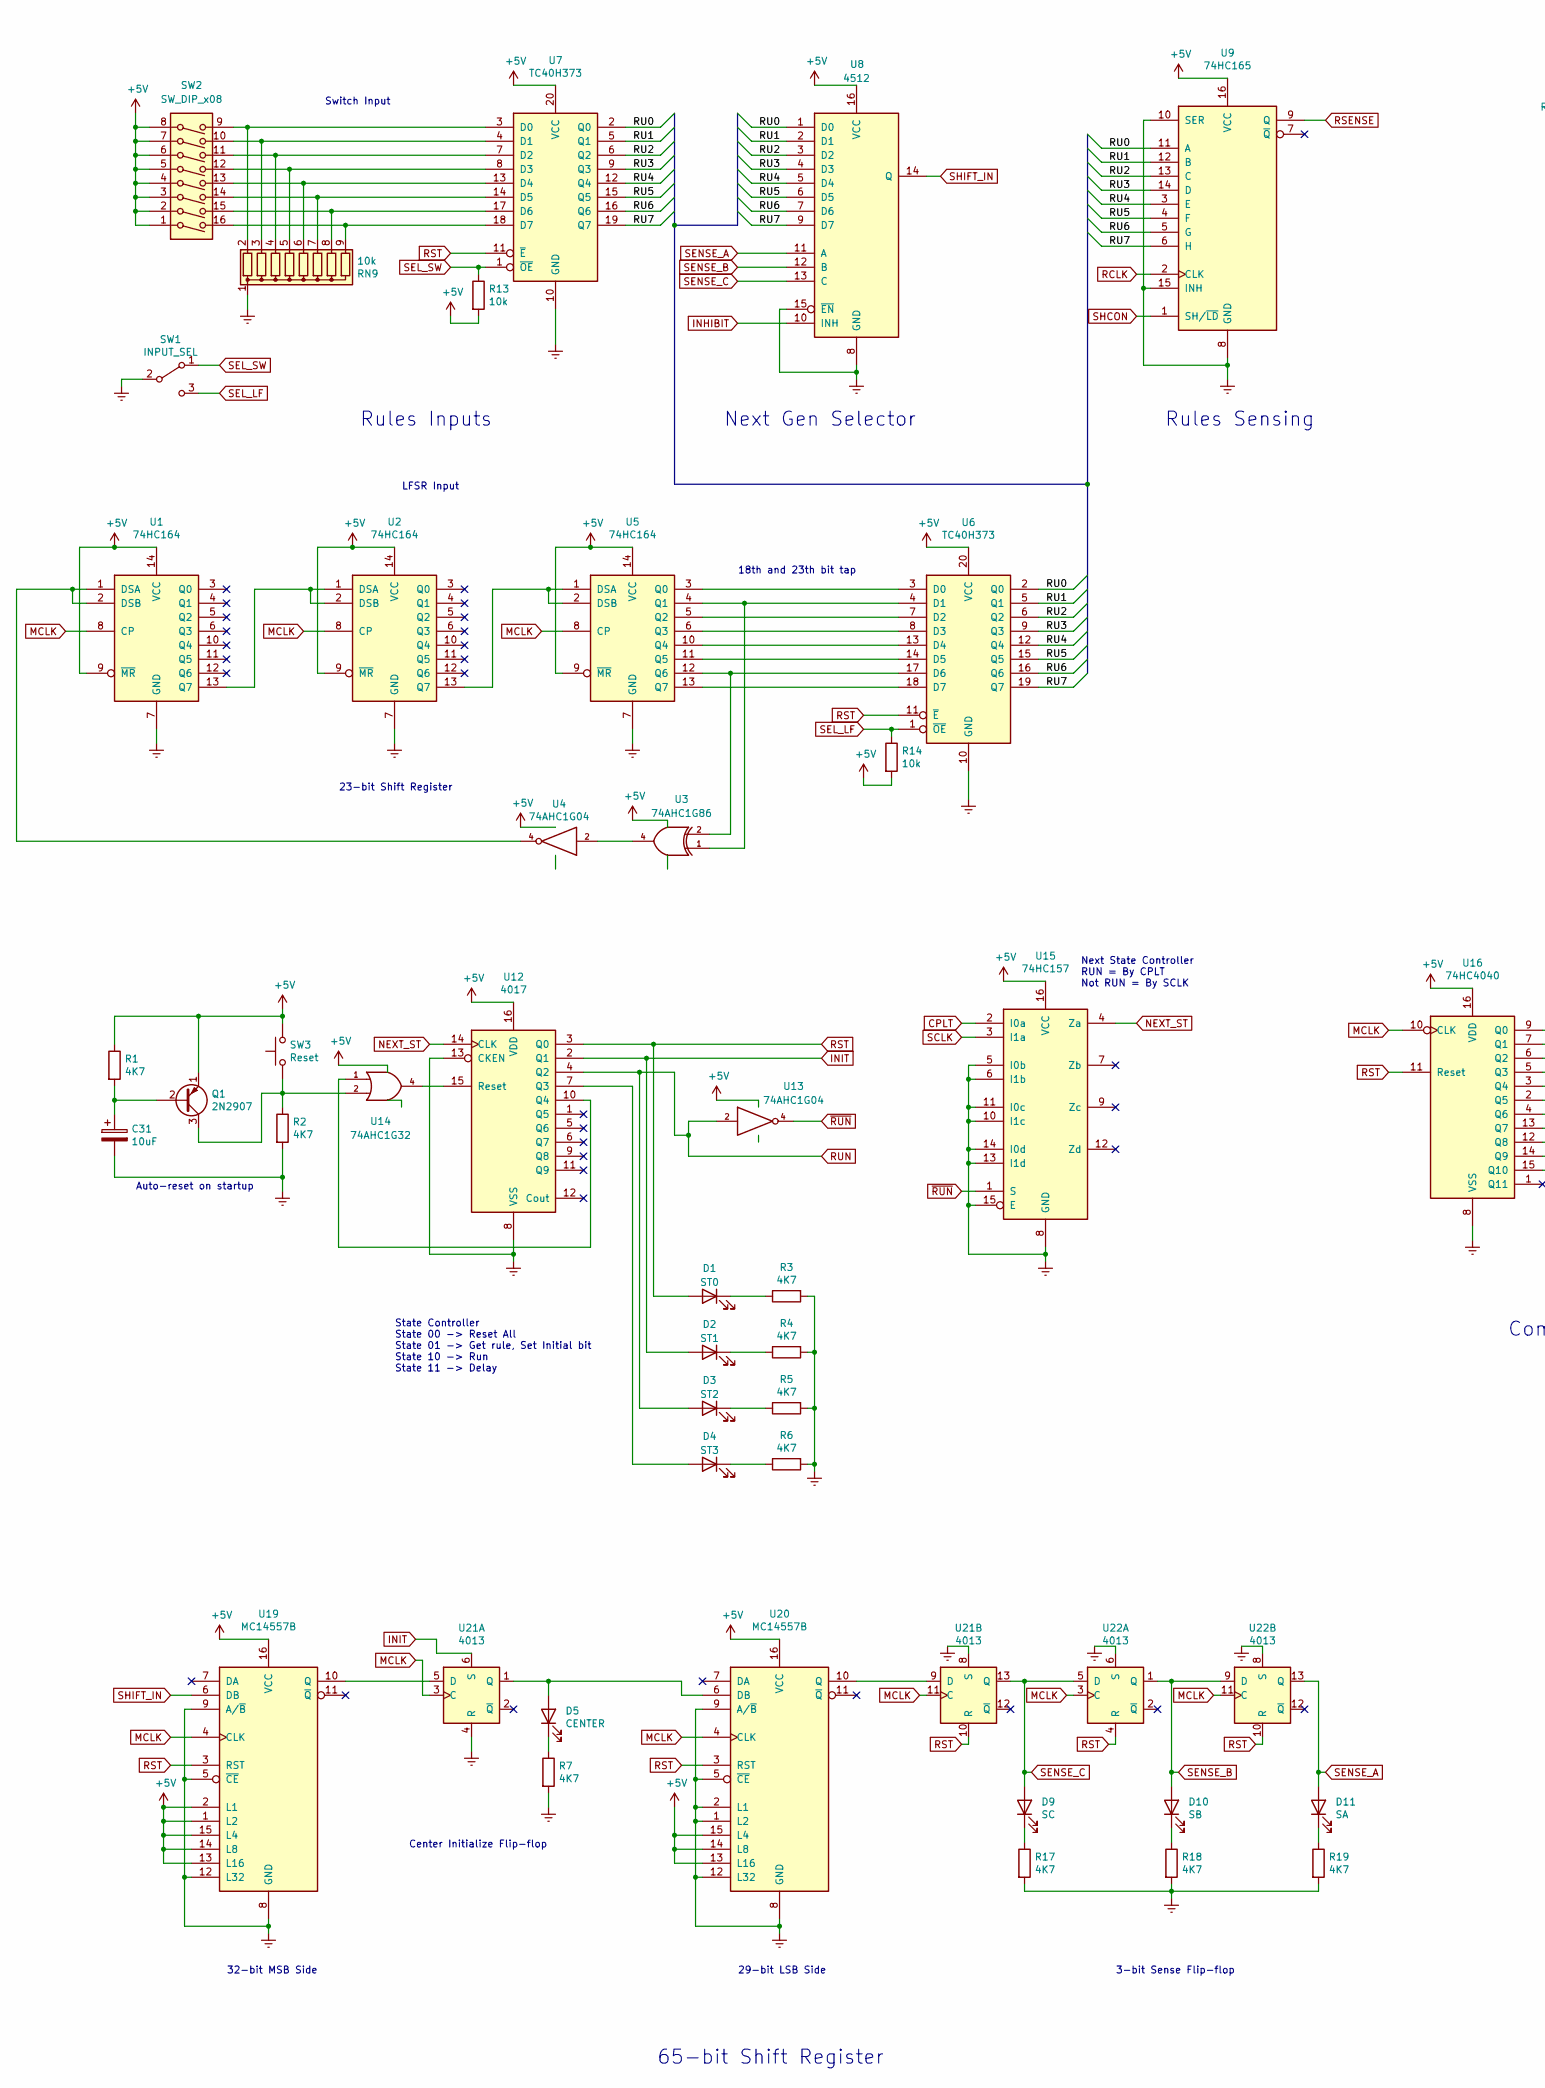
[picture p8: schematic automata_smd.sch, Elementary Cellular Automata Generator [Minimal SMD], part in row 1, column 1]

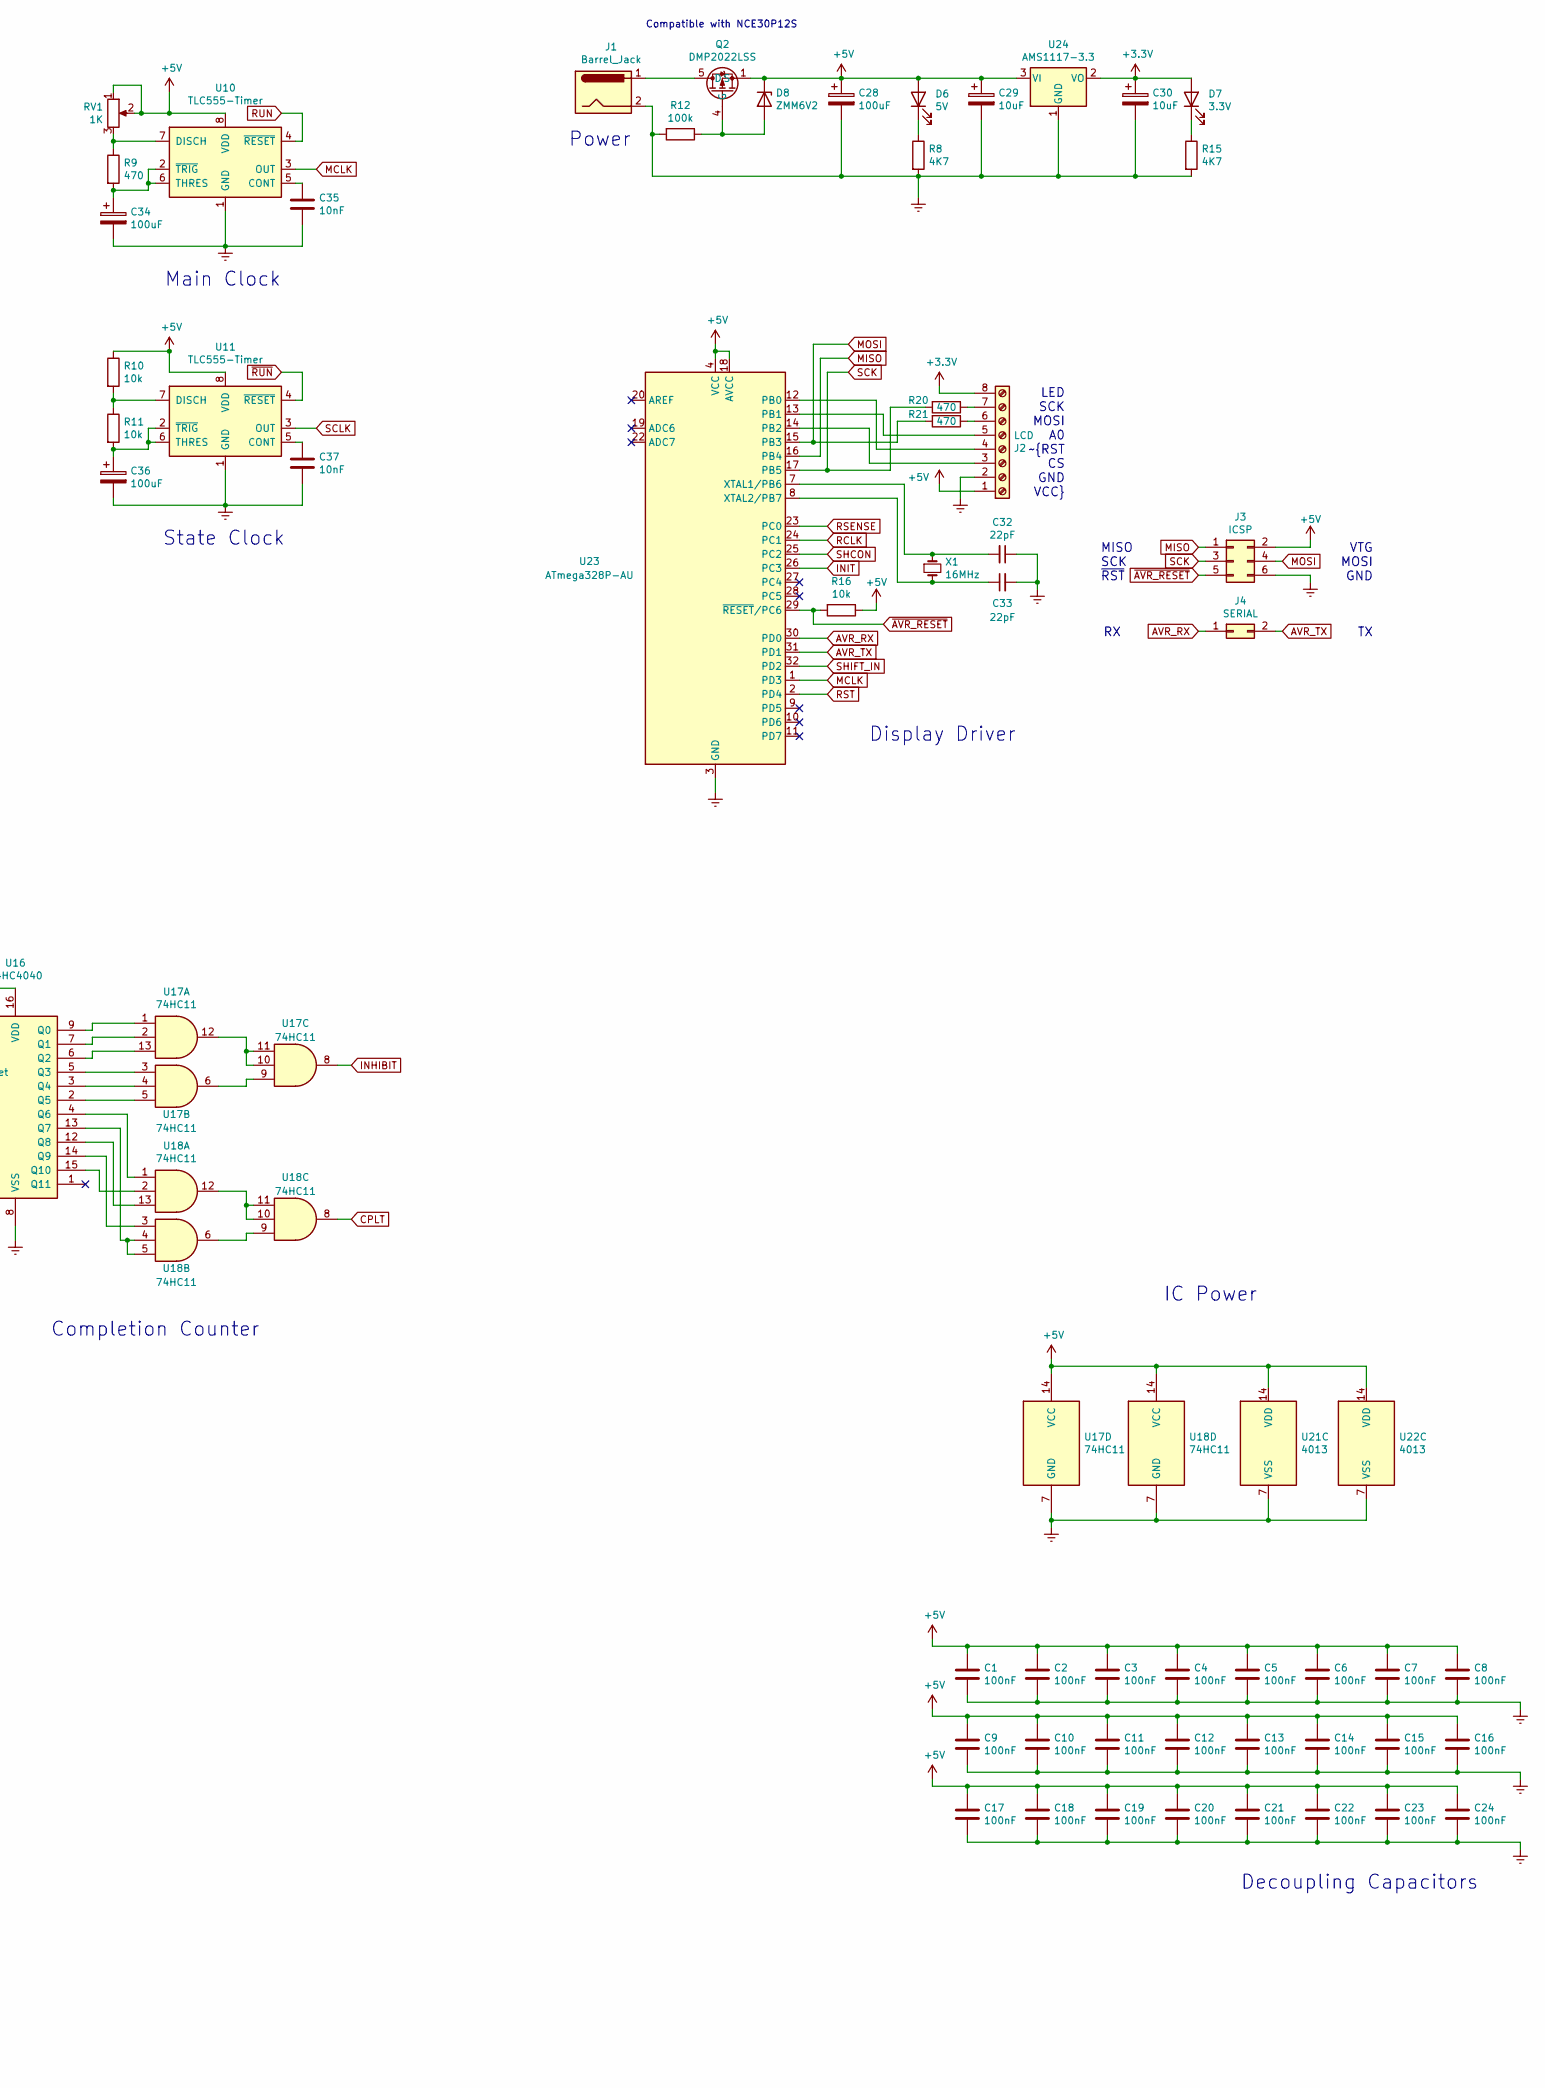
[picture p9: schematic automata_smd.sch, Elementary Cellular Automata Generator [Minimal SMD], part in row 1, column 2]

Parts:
C1: 100nF; TSSOP-14_4.4x5mm_P0.65mm
C2, C3, C4, C5, C6, C7, C8, C9, C10, C11, C12, C13, C14, C15, C16, C17, C18, C19, C20, C21, C22, C23, C24: 100nF; C_0603_1608Metric
C28, C34, C36: 100uF; CP_Radial_D8.0mm_P2.50mm
C29, C30, C31: 10uF; CP_Radial_D5.0mm_P2.00mm
C32, C33: 22pF; C_0603_1608Metric
C35, C37: 10nF; C_0603_1608Metric
D1: ST0; LED_0603_1608Metric
D2: ST1; LED_0603_1608Metric
D3: ST2; LED_0603_1608Metric
D4: ST3; LED_0603_1608Metric
D5: CENTER; LED_0603_1608Metric
D6: 5V; LED_0603_1608Metric
D7: 3.3V; LED_0603_1608Metric
D8: ZMM6V2; D_MiniMELF
D9: SC; LED_0603_1608Metric
D10: SB; LED_0603_1608Metric
D11: SA; LED_0603_1608Metric
J1: Barrel_Jack; BarrelJack_Horizontal
J2: LCD; PinHeader_1x08_P2.54mm_Vertical
J3: ICSP; PinHeader_2x03_P2.54mm_Vertical
J4: SERIAL; PinHeader_2x01_P2.54mm_Vertical
Q1: 2N2907; SOT-23
Q2: DMP2022LSS; SO-8_3.9x4.9mm_P1.27mm
R1, R2, R3, R4, R5, R6, R7, R8, R15, R17, R18, R19: 4K7; R_0603_1608Metric
R9, R20, R21: 470; R_0603_1608Metric
R10, R11, R13, R14, R16: 10k; R_0603_1608Metric
R12: 100k; R_0603_1608Metric
RN9: 10k; R_Array_SIP9
RV1: 1K; 3362P_1
SW1: INPUT_SEL; OS102011MA1QN1
SW2: SW_DIP_x08; SW_DIP_SPSTx08_Slide_9.78x22.5mm_W7.62mm_P2.54mm
SW3: Reset; SW_PUSH_6mm
U1, U2, U5: 74HC164; TSSOP-14_4.4x5mm_P0.65mm
U3: 74AHC1G86; SOT-23-5
U4, U13: 74AHC1G04; SOT-23-5
U6, U7: TC40H373; TSSOP-20_4.4x6.5mm_P0.65mm
U8: 4512; TSSOP-16_4.4x5mm_P0.65mm
U9: 74HC165; TSSOP-16_4.4x5mm_P0.65mm
U10, U11: TLC555-Timer; SOIC-8_3.9x4.9mm_P1.27mm
U12: 4017; TSSOP-16_4.4x5mm_P0.65mm
U14: 74AHC1G32; SOT-23-5
U15: 74HC157; TSSOP-16_4.4x5mm_P0.65mm
U16: 74HC4040; TSSOP-16_4.4x5mm_P0.65mm
U17, U18: 74HC11; TSSOP-14_4.4x5mm_P0.65mm
U19, U20: MC14557B; SOIC-16W_7.5x10.3mm_P1.27mm
U21, U22: 4013; TSSOP-14_4.4x5mm_P0.65mm
U23: ATmega328P-AU; TQFP-32_7x7mm_P0.8mm
U24: AMS1117-3.3; SOT-223-3_TabPin2
X1: 16MHz; Crystal_SMD_5032-2Pin_5.0x3.2mm

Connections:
+3V3: C30.1, D7.2 (A), J2.8, U24.2 (VO)
/RU0: U6.2 (Q0), U7.2 (Q0), U8.1 (D0), U9.11 (A)
/RU1: U6.5 (Q1), U7.5 (Q1), U8.2 (D1), U9.12 (B)
/RU2: U6.6 (Q2), U7.6 (Q2), U8.3 (D2), U9.13 (C)
/RU3: U6.9 (Q3), U7.9 (Q3), U8.4 (D3), U9.14 (D)
/RU4: U6.12 (Q4), U7.12 (Q4), U8.5 (D4), U9.3 (E)
/RU5: U6.15 (Q5), U7.15 (Q5), U8.6 (D5), U9.4 (F)
/RU6: U6.16 (Q6), U7.16 (Q6), U8.7 (D6), U9.5 (G)
/RU7: U6.19 (Q7), U7.19 (Q7), U8.9 (D7), U9.6 (H)
AVR_RX: J4.1, U23.30 (PD0)
AVR_TX: J4.2, U23.31 (PD1)
CPLT: U15.2 (I0a), U18.8
INHIBIT: U8.10 (INH), U17.8
INIT: D2.2 (A), U12.2 (Q1), U21.6 (S), U23.26 (PC3)
MCLK: U1.8 (CP), U2.8 (CP), U5.8 (CP), U10.3 (OUT), U16.10 (CLK), U19.4 (CLK), U20.4 (CLK), U21.3 (C), U21.11 (C), U22.3 (C), U22.11 (C), U23.1 (PD3)
MISO: J3.1, U23.16 (PB4)
MOSI: J3.4, R21.2, U23.15 (PB3)
NEXT_ST: U12.14 (CLK), U15.4 (Za)
unnamed: C31.1, Q1.2 (B), R1.2
unnamed: C32.2, U23.7 (XTAL1/PB6), X1.1
unnamed: C33.1, U23.8 (XTAL2/PB7), X1.2
unnamed: C34.1, R9.2, U10.2 (~TRIG), U10.6 (THRES)
unnamed: C35.1, U10.5 (CONT)
unnamed: C36.1, R11.2, U11.2 (~TRIG), U11.6 (THRES)
unnamed: C37.1, U11.5 (CONT)
unnamed: D1.1 (K), R3.1
unnamed: D2.1 (K), R4.1
unnamed: D3.1 (K), R5.1
unnamed: D4.1 (K), R6.1
unnamed: D4.2 (A), U12.7 (Q3)
unnamed: D5.1 (K), R7.1
unnamed: D5.2 (A), U20.6 (DB), U21.1 (Q)
unnamed: D6.1 (K), R8.1
unnamed: D7.1 (K), R15.1
unnamed: D8.2 (A), Q2.4 (G), R12.1
unnamed: D9.1 (K), R17.1
unnamed: D10.1 (K), R18.1
unnamed: D11.1 (K), R19.1
unnamed: J1.1, Q2.5 (D), Q2.6 (D), Q2.7 (D), Q2.8 (D)
unnamed: J2.3, U23.14 (PB2)
unnamed: J2.4, U23.12 (PB0)
unnamed: J2.5, U23.13 (PB1)
unnamed: J2.6, R21.1
unnamed: J2.7, R20.1
unnamed: Q1.3 (C), R2.1, SW3.1, U14.2
unnamed: R9.1, RV1.3, U10.7 (DISCH)
unnamed: R10.2, R11.1, U11.7 (DISCH)
unnamed: RN9.2 (R1), SW2.9, U7.3 (D0)
unnamed: RN9.3 (R2), SW2.10, U7.4 (D1)
unnamed: RN9.4 (R3), SW2.11, U7.7 (D2)
unnamed: RN9.5 (R4), SW2.12, U7.8 (D3)
unnamed: RN9.6 (R5), SW2.13, U7.13 (D4)
unnamed: RN9.7 (R6), SW2.14, U7.14 (D5)
unnamed: RN9.8 (R7), SW2.15, U7.17 (D6)
unnamed: RN9.9 (R8), SW2.16, U7.18 (D7)
unnamed: U1.1 (DSA), U1.2 (DSB), U4.4
unnamed: U1.13 (Q7), U2.1 (DSA), U2.2 (DSB)
unnamed: U2.13 (Q7), U5.1 (DSA), U5.2 (DSB)
unnamed: U3.1, U5.4 (Q1), U6.4 (D1)
unnamed: U3.2, U5.12 (Q6), U6.17 (D6)
unnamed: U3.4, U4.2
unnamed: U5.3 (Q0), U6.3 (D0)
unnamed: U5.5 (Q2), U6.7 (D2)
unnamed: U5.6 (Q3), U6.8 (D3)
unnamed: U5.10 (Q4), U6.13 (D4)
unnamed: U5.11 (Q5), U6.14 (D5)
unnamed: U5.13 (Q7), U6.18 (D7)
unnamed: U12.10 (Q4), U14.1
unnamed: U12.15 (Reset), U14.4
unnamed: U16.2 (Q5), U17.5
unnamed: U16.3 (Q4), U17.4
unnamed: U16.4 (Q6), U18.1
unnamed: U16.5 (Q3), U17.3
unnamed: U16.6 (Q2), U17.13
unnamed: U16.7 (Q1), U17.2
unnamed: U16.9 (Q0), U17.1
unnamed: U16.12 (Q8), U18.13
unnamed: U16.13 (Q7), U18.4, U18.5
unnamed: U16.14 (Q9), U18.3
unnamed: U16.15 (Q10), U18.2
unnamed: U17.6, U17.9
unnamed: U17.10, U17.11, U17.12
unnamed: U18.6, U18.9
unnamed: U18.10, U18.11, U18.12
unnamed: U19.10 (Q), U21.5 (D)
unnamed: U20.10 (Q), U21.9 (D)
RCLK: U9.2 (CLK), U23.24 (PC1)
RSENSE: U9.9 (Q), U23.23 (PC0)
RST: D1.2 (A), U6.11 (~E), U7.11 (~E), U12.3 (Q0), U16.11 (Reset), U19.3 (RST), U20.3 (RST), U21.10 (R), U22.4 (R), U22.10 (R), U23.2 (PD4)
RUN: D3.2 (A), U10.4 (~RESET), U12.4 (Q2), U13.2
SCK: J3.3, R20.2, U23.17 (PB5)
SCLK: U11.3 (OUT), U15.3 (I1a)
SEL_LF: R14.1, SW1.3 (C), U6.1 (~OE)
SEL_SW: R13.1, SW1.1 (A), U7.1 (~OE)
SENSE_A: D11.2 (A), U8.11 (A), U22.13 (Q)
SENSE_B: D10.2 (A), U8.12 (B), U22.1 (Q), U22.9 (D)
SENSE_C: D9.2 (A), U8.13 (C), U21.13 (Q), U22.5 (D)
SHCON: U9.1 (SH/~LD), U23.25 (PC2)
SHIFT_IN: U8.14 (Q), U19.6 (DB), U23.32 (PD2)
~AVR_RESET: J3.5, R16.2, U23.29 (~RESET~/PC6)
~RUN: U11.4 (~RESET), U13.4, U15.1 (S)

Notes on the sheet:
Switch Input
Rules Inputs
Next Gen Selector
Completion Counter
LED SCK MOSI A0 ~RST CS GND VCC
Power
Display Driver
Rules Sensing
State Controller State 00 -> Reset All State 01 -> Get rule, Set Initial bit State 10 -> Run State 11 -> Delay
Auto-reset on startup
State Clock
Next State Controller RUN = By CPLT Not RUN = By SCLK
65-bit Shift Register
Center Initialize Flip-flop
Main Clock
Decoupling Capacitors
IC Power
32-bit MSB Side
29-bit LSB Side
3-bit Sense Flip-flop
MISO SCK ~RST
VTG MOSI GND
Compatible with NCE30P12S
LFSR Input
23-bit Shift Register
18th and 23th bit tap

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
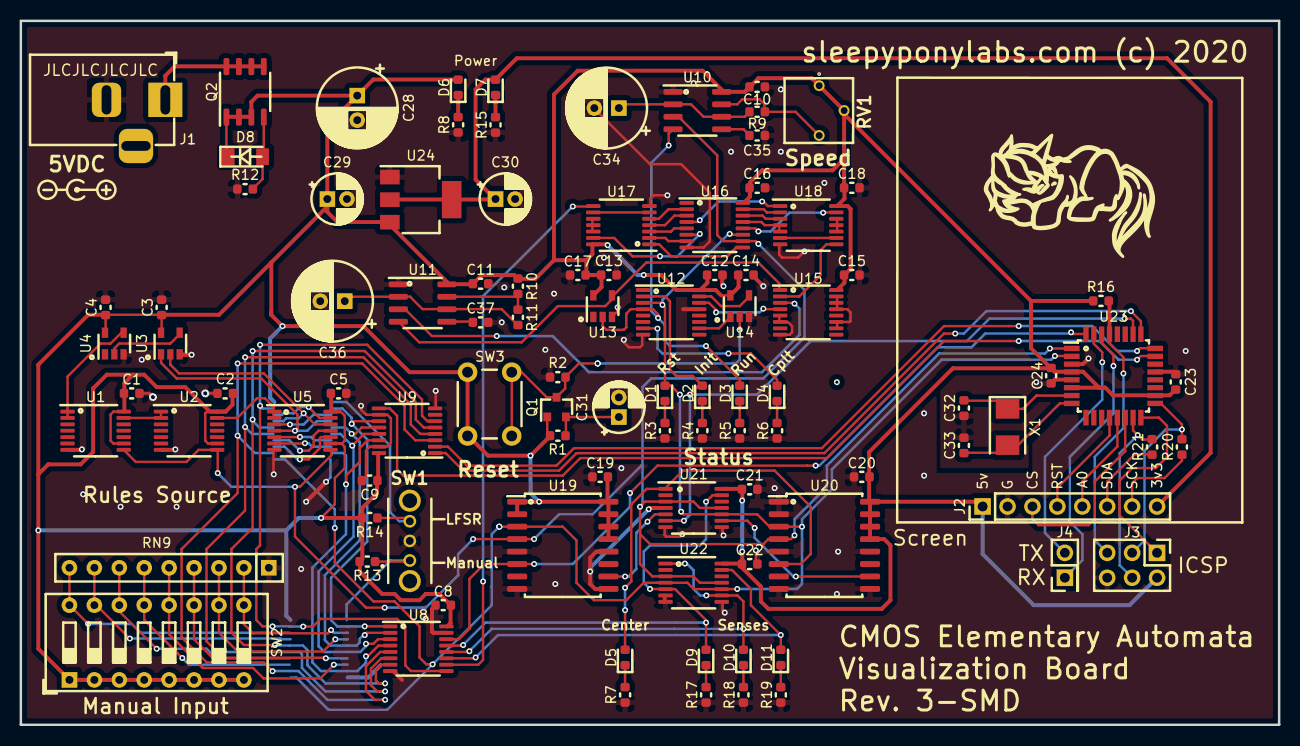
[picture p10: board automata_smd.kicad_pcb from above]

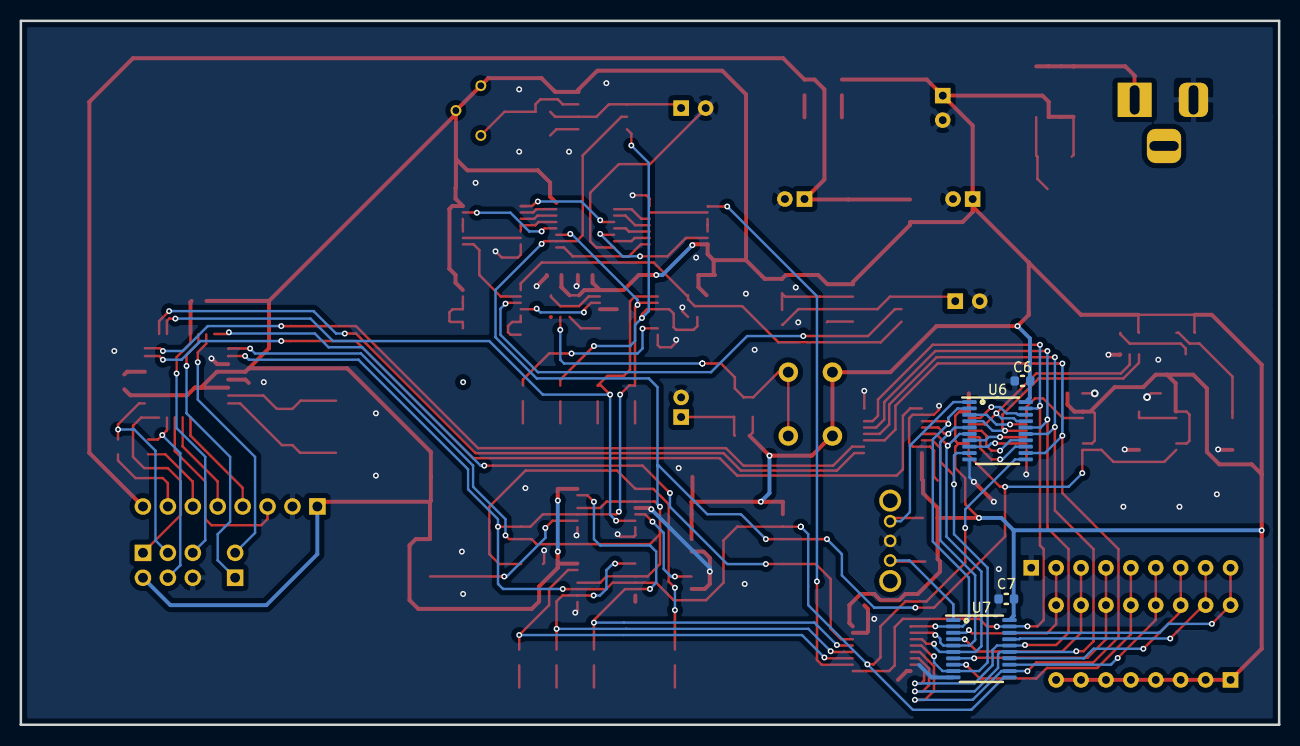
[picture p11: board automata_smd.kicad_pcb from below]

Board: 2 copper layers, 128.3 x 71.8 mm, 104 parts (4 on the bottom side), 103 nets.

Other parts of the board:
G1: LOGO; sleepylogo_20mm
REF1: Symbol_Barrel_Polarity

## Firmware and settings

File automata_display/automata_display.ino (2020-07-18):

/*#include "uTFT_ST7735.h"

#define RESET 0
#define INIT 1
#define RUN 2

void myDelay(int16_t ms);

bool newValue = false, updateFlag = false;

int currentState = RESET;

void receiveNewPixel() {
  newValue = PINB & 0b0001;
  updateFlag = true;
}

uint8_t readRules() {
  uint8_t res = 0, mult = 1;
  //interfacing with the 74HC165 shift register
  //step 1: load values
  PORTA |= (1 << 2);
  myDelay(5);
  PORTA &= ~(1 << 2);
  myDelay(5);
  
  //step 2: read value and shift to next bit
  for(int i = 0; i < 8; i++)
  {
    res += (PINA & 1) * mult;
    mult *= 2;

    PORTA |= (1 << 1);
    myDelay(5);
    PORTA &= ~(1 << 1);
    myDelay(5);    
  }

  return res;
}

void setup() {
  // init ports
  // PA0, PA3 in | PA1, PA2 out | PA4, PA5, PA6 uTFT | PA7 vacant
  // enable pullups for now
  DDRA = 0b01110110;
  PORTA = 0b10001101;

  // PB0, PB1, PB2 in | PB3 uTFT
  // enable pullups for now
  DDRB = 0b1000;
  PORTB = 0b0111;
  
  // init screen
  // ATTINY84 profile, ST7735, 128*128 1.44" TFT display
  ////init();
  ////fillScreen(Color565(0,0,0));

  //attach interrupt on pin PB2
  attachInterrupt(PB2, receiveNewPixel, RISING);
}

void loop() {
  
  //check for state changes
  if(PINB & 0x0010 == false)
    currentState = RESET;
  else if(PINA & 0x00001000 == true)
    currentState = INIT;
  else
    currentState = RUN;

  //perform operations for each state
  if(currentState == RESET)
  {
    //clear screen
  }
  else if(currentState == INIT)
  {
    //read the current rule number and show on the screen
    //something = readRules();
  }
  else
  {
    if(updateFlag == true)
    {
      updateFlag = false;

      //add a new pixel to screen
    }
  }
}
*/

#include <SPI.h>
#include "Ucglib.h"

#define RESET 0
#define INIT 1
#define RUN 2
#define INITWAIT 3

#define ORIGIN_X 10
#define ORIGIN_Y 45

#define DEF_DRAW_X 126
#define DEF_DRAW_Y 70

bool newValue = false, updateFlag = false;

int currentState = RESET;
int posX, posY;

Ucglib_ST7735_18x128x160_HWSPI ucg(/*cd=*/ 9, /*cs=*/ 10, /*reset=*/ 8);

void receiveNewPixel() {
  newValue = (PIND & 0b00000100) >> 2;
  updateFlag = true;
}

uint8_t readRules() {
  uint8_t res = 0, mult = 128;
  //interfacing with the 74HC165 shift register
  //step 1: load values
  PORTC &= ~(1 << 2);
  //delay(5);
  PORTC |= (1 << 2);
  //delay(5);
  
  //step 2: read value and shift to next bit
  for(int i = 0; i < 8; i++)
  {
    res += (PINC & 1) * mult;
    mult /= 2;

    PORTC |= (1 << 1);
    //delay(5);
    PORTC &= ~(1 << 1);
    //delay(5);    
  }

  return res;
}

void attemptStateChange() {
  
  //check for state changes
  if(currentState == RUN && (PIND & 0b00010000) == 0b00010000)
    currentState = RESET;
  else if(currentState == RESET)
    currentState = INITWAIT;
  else if(currentState == INITWAIT && (PINC & 0b0001000) == 0b0001000)
    currentState = INIT;
  else if(currentState == INIT)
    currentState = RUN; 
}

void setup() {
  // init ports
  // PC0, PC3 in | PC1, PC2 out | PC6 reserved | PC4 - PC5 vacant
  // enable pullups for now
  DDRC |= 0b0000110;
  DDRC &= ~(0b0001001);
  PORTC |= 0b0001101;
  PORTC &= ~(0b0000010);

  // PD2 - PD4 in | PD0, PD1 reserved | PD5 - PD7 vacant
  // enable pullups for now
  DDRD &= ~(0b00011100);
  PORTD |= 0b00011100;
  
  // init screen
  // ATMEGA328P profile, ST7735, 128*160 1.8" TFT display
  ucg.begin(UCG_FONT_MODE_TRANSPARENT);
  ucg.setFont(ucg_font_ncenR08_hr);
  ucg.setRotate180();
  ucg.clearScreen();

  delay(5);
  ucg.setPrintPos(ORIGIN_X, ORIGIN_Y);    //this is the upper-left corner of the screen
  ucg.print("Initialized");
  delay(200);

  //attach interrupt on pin PD3
  attachInterrupt(1, receiveNewPixel, RISING);
}

void loop() {

  //perform operations for each state
  if(currentState == RESET)
  {
    //clear screen
    ucg.clearScreen();

    //make background white
    ucg.setColor(255, 255, 255);
    ucg.drawBox(0, 0, ucg.getWidth(), ucg.getHeight());

    //put required text in
    ucg.setColor(0, 0, 0);
    ucg.setPrintPos(ORIGIN_X, ORIGIN_Y);
    ucg.print("Current Rule: ");

    //reset drawing location
    posX = DEF_DRAW_X;
    posY = DEF_DRAW_Y;

    //set drawing color
    ucg.setColor(255, 0, 0);

    attemptStateChange();
  }
  else if(currentState == INIT)
  {
    //read the current rule number and show on the screen
    ucg.print(readRules());

    //draw the initial bit on the center of first line
    ucg.drawBox(posX-60, posY-2, 2, 2);

    attemptStateChange();
  }
  else
  {
    if(updateFlag == true)
    {
      //clear flag
      updateFlag = false;

      //set draw position and draw if newValue is true
      if(newValue == 1)
        ucg.drawBox(posX, posY, 2, 2);

      //move to next drawing location
      posX-=2;

      if(posX < 0)
      {
        posX = DEF_DRAW_X;
        posY+=2;
      }
    }
    
    attemptStateChange();
    delay(5);
  }
}

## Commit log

2020-05-16 revision 2
    [automata-B_Cu.gbr, automata-B_Mask.gbr, automata-B_SilkS.gbr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]
2020-05-19 Add pin 1 indicators to some parts in pcb (temporary)
    [automata_smd-B_Cu.gbr, automata_smd-B_Mask.gbr, automata_smd-B_SilkS.gbr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]
2020-07-16 Remove rescue libs and fixed MC14557 symbol error
    [automata.kicad_pcb, automata.sch, automata_smd.kicad_pcb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]
2020-07-18 Modified display driver code
2020-07-18 Rev 3 design update for SMD version
    [automata_smd-B_Cu.gbr, automata_smd-B_Mask.gbr, automata_smd-B_SilkS.gbr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]
2020-07-19 Rev 3 design update for standard version
    [automata-B_Cu.gbr, automata-B_Mask.gbr, automata-B_SilkS.gbr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]
2020-08-26 Changed LED bargraphs to 10-bar variant
    [automata.kicad_pcb, automata.sch]
2020-08-26 Document update
    [automata.kicad_pcb, automata.sch]
2020-09-12 LDO change to streamline the inventory
    [automata-B_Cu.gbr, automata-B_Mask.gbr, automata-B_SilkS.gbr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]

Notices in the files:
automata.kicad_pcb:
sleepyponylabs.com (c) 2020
